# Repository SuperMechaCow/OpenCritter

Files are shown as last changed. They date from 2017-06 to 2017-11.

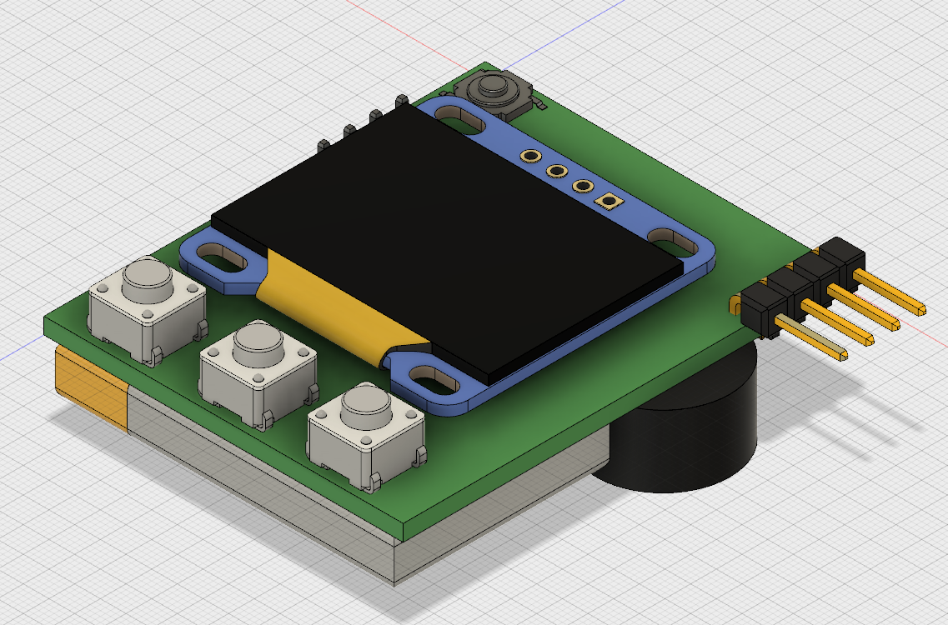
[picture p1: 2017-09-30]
hardware/oc_DevKit2/images/Capture1.PNG

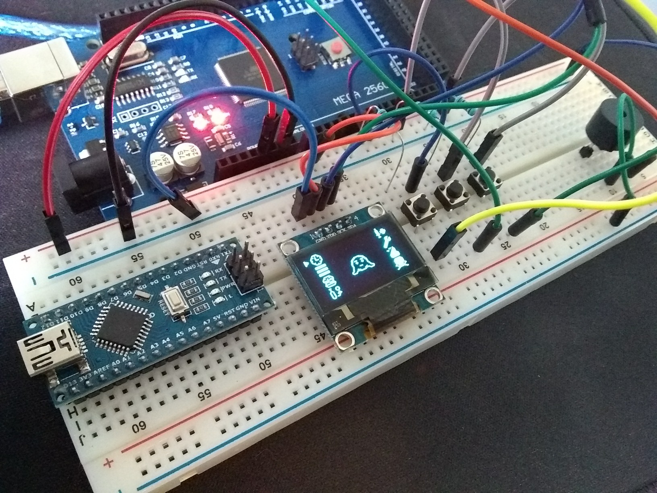
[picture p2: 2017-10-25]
gfx/media/projects/IMG_20171016_145721863.jpg

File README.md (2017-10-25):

# OpenCritter

OpenCritter is an open source digital pet. The software is totally free, and the hardware easy to obtain.

Anyone is invited to work on the project for as long as they stick to the following principles:

- OpenCritter is for all levels of skill and expertise. Novices should be able to build their own from scratch, and experts can lead the project development.
- OpenCritter is all-ages and gender nuetral.
- OpenCritter is for makers *and* hackers. Create and destroy!
- Mods are encouraged! But anything that conflicts with the "core experience" of the game should be listed as a new branch.

## Community

**Main GitHub:**
https://github.com/SuperMechaCow/OpenCritter

**Subreddit:**
https://www.reddit.com/r/OpenCritter/

**Discord Channel:**
https://discord.gg/VW9fjV9

## Community

**Main GitHub:**
https://github.com/SuperMechaCow/OpenCritter

**Subreddit:**
https://www.reddit.com/r/OpenCritter/

**Discord Channel:**
https://discord.gg/VW9fjV9

## Hardware

OpenCritter is currently being developed for ESP-01 and NodeMCU in the Arduino IDE. A branch is being made for Atmega328p-based "Lite" versions.

**DevKit1** has been released. It features an ESP8266 circuit, an alternative header for an ESP-01 module, an Atmega328p circuit, programming headers, and four i2c bus headers.

All platforms will need an I2C 0.96" OLED screen based on SSD1306. Additonal piezo buzzer, a small vibration motor (optional), a battery circuit, and three tactile switches should be used with the platform or as an additional IOPU device.

## Software

Currently, the software requires Adafruit's GFX and SSD1306 libraries, and ESP8266 core arduino software depending on your platform.

## Objectives

- Finish the main game's functionality (sickness/death, crying for attention, evolution, mini-games, game rules)
- Add robust "plug-in device" support for modularity.
- Add peer-to-peer wireless communications
- Multi-player games and functions
- OpenCritter "dog house" device or wireless internet functionality.
- OpenCritter database for online multiplayer/scoreboards.

## How can I contribute?

- Graphic designer? We need sprites and animations for 30 different critters!
- Web front-end developer? We need a more robust and pretty webapp to be hosted by the device itself!
- Web back-end developer? We need a database / highscore table for the pets to connect to/register/sync with!
- 3D CAD? DevKit1 could benefit from some open-source cases!
- Electronics Engineer? We need new i2c modules to add plug-and-play functions to the device!
- Software/Embedded Engineer? The device is always in need of optimization, improved i2c module API, and power-saving features!
- Stickler for details? Documentation constantly needs updated!

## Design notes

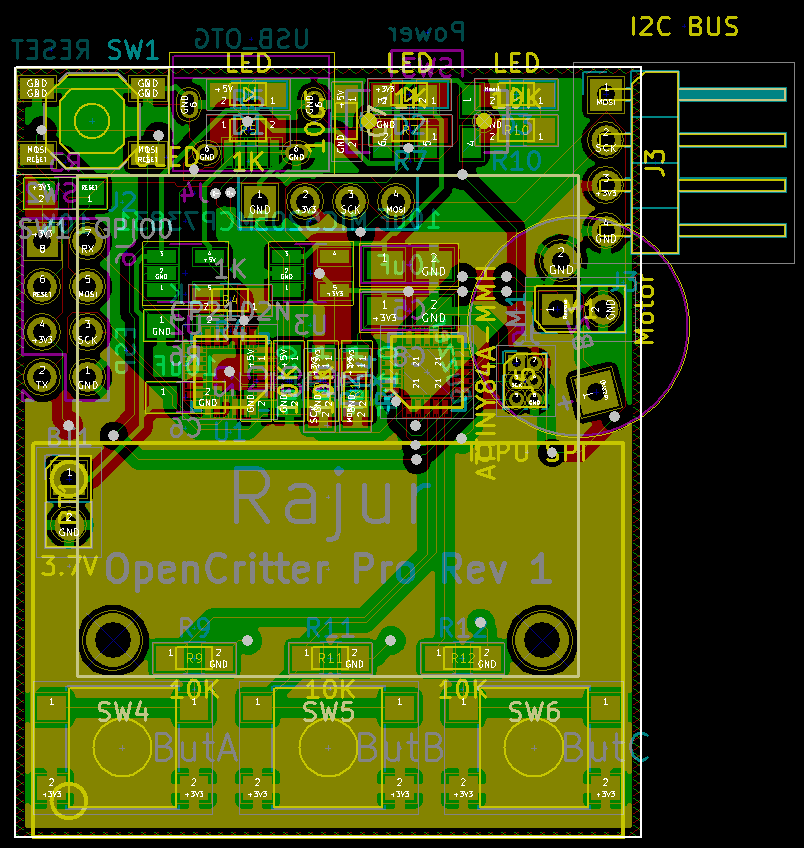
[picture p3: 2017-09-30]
hardware/oc_DevKit2/images/19e5b5ffc640fa55cabdfcedfeb329e0.png

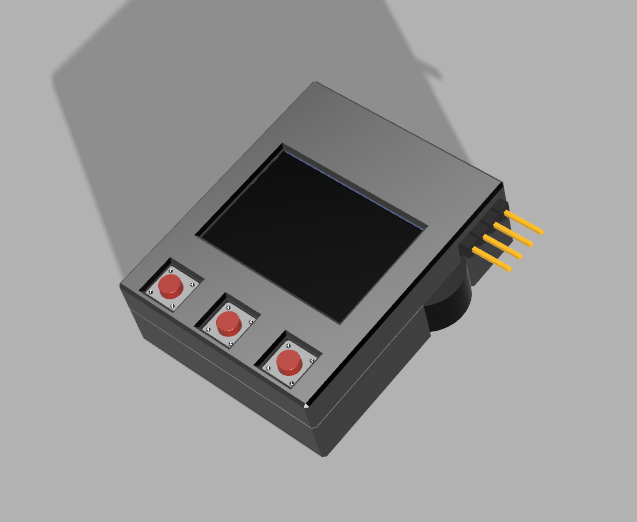
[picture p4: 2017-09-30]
hardware/oc_DevKit2/images/Capture.PNG

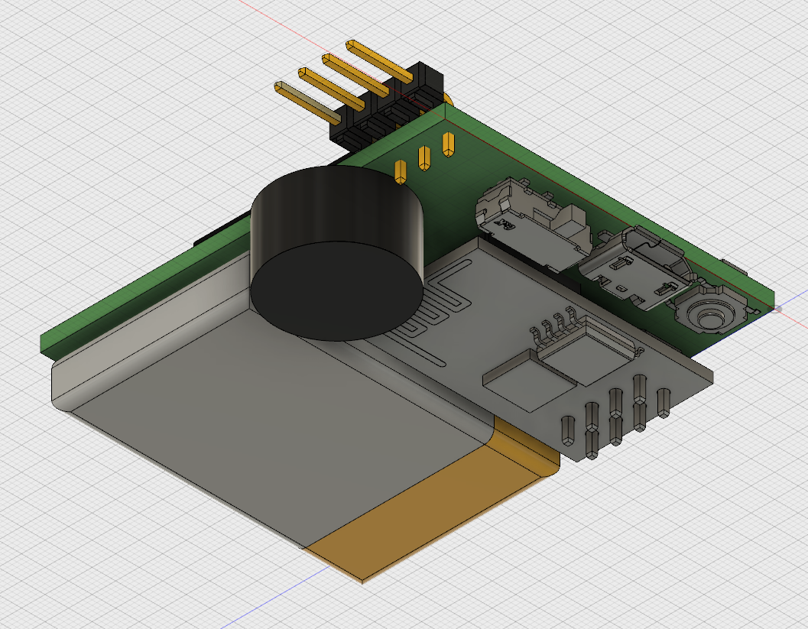
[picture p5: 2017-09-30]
hardware/oc_DevKit2/images/Capture2.PNG

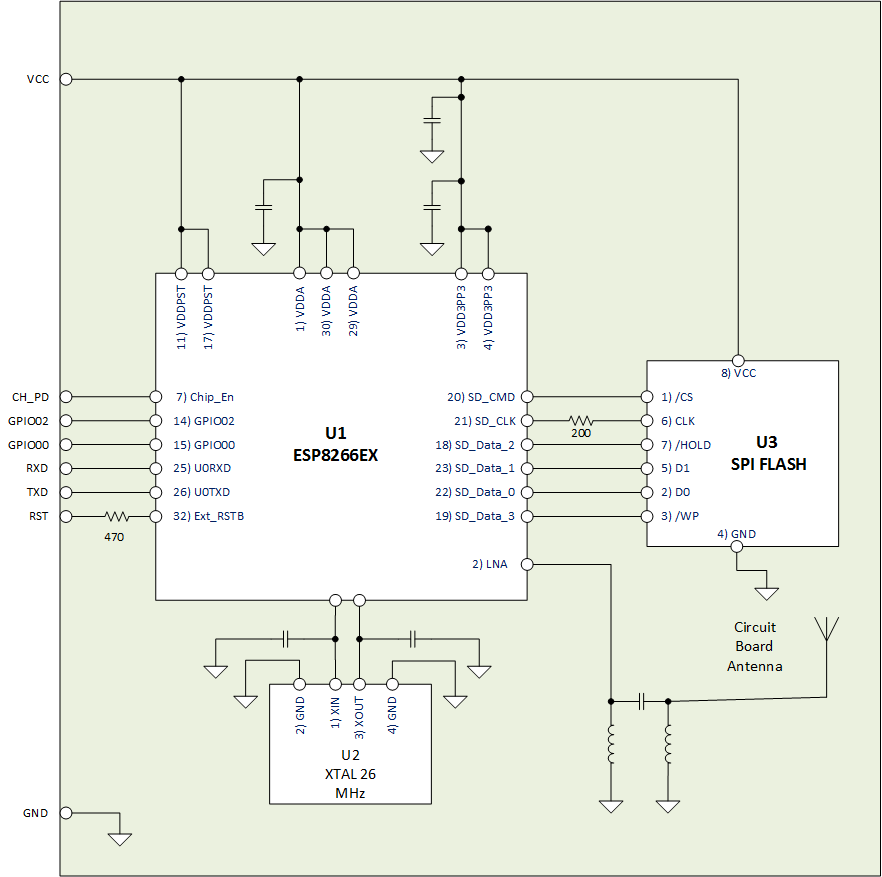
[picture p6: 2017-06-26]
reference/ESP01-Schematic.png

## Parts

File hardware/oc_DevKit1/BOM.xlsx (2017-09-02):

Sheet: Sheet1
version | source | date | tool | number | name | tstamps | title | company | rev | date2 | source3 | number4 | value | ref | value2 | footprint | lib | part | names | tstamps3 | tstamp | datasheet | lib4 | part5 | alias | description | docs | field | name6 | num | name7 | type | fp | logical | uri | code | name8 | ref9 | pin
D | C:/Users/christopher.smith/ownCloud/Projects/OpenCritter/hardware/opencritter_pro/opencritter.sch | 9/1/2017 12:39:36 PM | Eeschema 4.0.6 | 1 | / | / | OpenCritter DevKit1 | MechaMods | 1 | 2017-09-01 | opencritter.sch | 1
D | C:/Users/christopher.smith/ownCloud/Projects/OpenCritter/hardware/opencritter_pro/opencritter.sch | 9/1/2017 12:39:36 PM | Eeschema 4.0.6 | 1 | / | / | OpenCritter DevKit1 | MechaMods | 1 | 2017-09-01 | opencritter.sch | 2
D | C:/Users/christopher.smith/ownCloud/Projects/OpenCritter/hardware/opencritter_pro/opencritter.sch | 9/1/2017 12:39:36 PM | Eeschema 4.0.6 | 1 | / | / | OpenCritter DevKit1 | MechaMods | 1 | 2017-09-01 | opencritter.sch | 3
D | C:/Users/christopher.smith/ownCloud/Projects/OpenCritter/hardware/opencritter_pro/opencritter.sch | 9/1/2017 12:39:36 PM | Eeschema 4.0.6 | 1 | / | / | OpenCritter DevKit1 | MechaMods | 1 | 2017-09-01 | opencritter.sch | 4
D | C:/Users/christopher.smith/ownCloud/Projects/OpenCritter/hardware/opencritter_pro/opencritter.sch | 9/1/2017 12:39:36 PM | Eeschema 4.0.6 | 2 | /IOPU/ | /5984AD37/ | OpenCritter DevKit1 | MechaMods | 1 | 2017-09-01 | IOPU.sch | 1
D | C:/Users/christopher.smith/ownCloud/Projects/OpenCritter/hardware/opencritter_pro/opencritter.sch | 9/1/2017 12:39:36 PM | Eeschema 4.0.6 | 2 | /IOPU/ | /5984AD37/ | OpenCritter DevKit1 | MechaMods | 1 | 2017-09-01 | IOPU.sch | 2
D | C:/Users/christopher.smith/ownCloud/Projects/OpenCritter/hardware/opencritter_pro/opencritter.sch | 9/1/2017 12:39:36 PM | Eeschema 4.0.6 | 2 | /IOPU/ | /5984AD37/ | OpenCritter DevKit1 | MechaMods | 1 | 2017-09-01 | IOPU.sch | 3
D | C:/Users/christopher.smith/ownCloud/Projects/OpenCritter/hardware/opencritter_pro/opencritter.sch | 9/1/2017 12:39:36 PM | Eeschema 4.0.6 | 2 | /IOPU/ | /5984AD37/ | OpenCritter DevKit1 | MechaMods | 1 | 2017-09-01 | IOPU.sch | 4
D | C:/Users/christopher.smith/ownCloud/Projects/OpenCritter/hardware/opencritter_pro/opencritter.sch | 9/1/2017 12:39:36 PM | Eeschema 4.0.6 | 3 | /ESP-01/ | /5984AD3F/ | OpenCritter DevKit1 | MechaMods | 1 | 2017-09-01 | ESP-01.sch | 1
D | C:/Users/christopher.smith/ownCloud/Projects/OpenCritter/hardware/opencritter_pro/opencritter.sch | 9/1/2017 12:39:36 PM | Eeschema 4.0.6 | 3 | /ESP-01/ | /5984AD3F/ | OpenCritter DevKit1 | MechaMods | 1 | 2017-09-01 | ESP-01.sch | 2
D | C:/Users/christopher.smith/ownCloud/Projects/OpenCritter/hardware/opencritter_pro/opencritter.sch | 9/1/2017 12:39:36 PM | Eeschema 4.0.6 | 3 | /ESP-01/ | /5984AD3F/ | OpenCritter DevKit1 | MechaMods | 1 | 2017-09-01 | ESP-01.sch | 3
D | C:/Users/christopher.smith/ownCloud/Projects/OpenCritter/hardware/opencritter_pro/opencritter.sch | 9/1/2017 12:39:36 PM | Eeschema 4.0.6 | 3 | /ESP-01/ | /5984AD3F/ | OpenCritter DevKit1 | MechaMods | 1 | 2017-09-01 | ESP-01.sch | 4
D
D
D
D
D
D
D
D
D
D
D
D
D
D
D
D
D
D
D
D
D
D
D
D
D
D
D
D
D
D
D
D
D
D
D
D
D
D
D
D
D
D
D
D
D
D
D
D
D
D
D
D
D
D
D
D
D
D
D
D
D
D
D
D
D
D
D
D
D
D
D
D
D
D
D
D
D
D
D
D
D
D
D
D
D
D
D
D
D
D
D
D
D
D
D
D
D
D
D
D
D
D
D
D
D
D
D
D
D
D
D
D
D
D
D
D
D
D
D
D
D
D
D
D
D
D
D
D
D
D
D
D
D
D
D
D
D
D
D
D
D
D
D
D
D
D
D
D
D
D
D
D
D
D
D
D
D
D
D
D
D
D
D
D
D
D
D
D
D
D
D
D
D
D
D
D
D
D
D
D
D
D
D
D
D
D
D
D
D
D
D
D
D
D
D
D
D
D
D
D
D
D
D
D
D
D
D
D
D
D
D
D
D
D
D
D
D
D
D
D
D
D
D
D
D
D
D
D
D
D
D
D
D
D
D
D
D
D
D
D
D
D
D
D
D
D
D
D
D
D
D
D
D
D
D
D
D
D
D
D
D
D
D
D
D
D
D
D
D
D
D
D
D
D
D
D
D
D
D
D
D
D
D
D
D
D
D
D
D
D
D
D
D
D
D
D
D
D
D
D
D
D
D
D
D
D
D
D
D
D
D
D
D
D
D
D
D
D
D
D
D
D
D
D
D
D
D
D
D
D
D
D
D
D
D
D
D
D
D
D
D
D
D
D
D
D
D
D
D
D
D
D
D
D
D
D
D
D
D
D
D
D
D
D
D
D
D
D
D
D
D
D
D
D
D
D
D
D
D
D
D
D
D
D
D
D
D
D
D
D
D
D
D
D
D
D
D
D
D
D
D
D
D
D
D
D
D
D
D
D
D
D
D
D
D
D
D
D
D
D
D
D
D
D
D
D
D
D
D
D
D
D
D
D
D
D
D
D
D
D
D
D
D
D
D
D
D
D
D
D
D
D
D
D
D
D
D
D
D
D
D
D
D
D
D
D
D
D
D
D
D
D
D
D
D
D
D
D
D
D
D
D
D

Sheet: Sheet2
ref | value5 | footprint | part | names | datasheet
AE1 | Antenna |  | Antenna | /ESP-01/
BT1 | Batter |  | Battery_Cell | /
BZ1 | Buzzer | Buzzers_Beepers:BUZZER | 490-4698-ND | /IOPU/ | http://www.murata.com/~/media/webrenewal/support/library/catalog/products/sound/p37e.ashx | https://www.digikey.com/product-detail/en/murata-electronics-north-america/PKM13EPYH4000-A0/490-4698-ND/1219329
C1 | 0.1uF | Capacitors_SMD:C_0805_HandSoldering | C | /IOPU/
C2 | 0.1uF | Capacitors_SMD:C_0805_HandSoldering | C | /IOPU/
C3 | 0.1uF | Capacitors_SMD:C_0805_HandSoldering | C | /IOPU/
C4 | C | Capacitors_SMD:C_0805_HandSoldering | C | /ESP-01/
C5 | C | Capacitors_SMD:C_0805_HandSoldering | C | /ESP-01/
C6 | C | Capacitors_SMD:C_0805_HandSoldering | C | /ESP-01/
C7 | C | Capacitors_SMD:C_0805_HandSoldering | C | /ESP-01/
C8 | C | Capacitors_SMD:C_0805_HandSoldering | C | /ESP-01/
D1 | LED | LEDs:LED_0805_HandSoldering | 732-4982-1-ND | /IOPU/ | http://katalog.we-online.de/led/datasheet/150080BS75000.pdf | https://www.digikey.com/product-detail/en/wurth-electronics-inc/150080BS75000/732-4982-1-ND/4489910
J1 | ESP UART | Pin_Headers:Pin_Header_Straight_1x04_Pitch2.54mm | S1012EC-22-ND | / | https://media.digikey.com/PDF/Data%20Sheets/Sullins%20PDFs/z%20RzCzzzSzzN-RC,%20ST,11635-B.pdf | https://www.digikey.com/product-detail/en/sullins-connector-solutions/PREC022SAAN-RC/S1012EC-22-ND/2774832
J10 | ESP Header |  |  | /ESP-01/
J11 | ESP GPIO | Pin_Headers:Pin_Header_Straight_1x08_Pitch2.54mm | J1 | /ESP-01/
J2 | 328 SPI | Pin_Headers:Pin_Header_Straight_2x03_Pitch2.54mm | J1 | /
J3 | OLED |  |  | /
J4 | 328 GPIO | Pin_Headers:Pin_Header_Straight_1x06_Pitch2.54mm | J1 | /
J5 | I2C BUS | Pin_Headers:Pin_Header_Angled_1x04_Pitch2.54mm | S1112EC-16-ND | / | https://media.digikey.com/PDF/Data%20Sheets/Sullins%20PDFs/zzzCzzzSzzN-M71RC,%2011637-B.pdf | https://www.digikey.com/product-detail/en/sullins-connector-solutions/PREC016SBAN-M71RC/S1112EC-16-ND/2774918
J6 | 328 UART | Pin_Headers:Pin_Header_Straight_1x04_Pitch2.54mm | J1 | /
J7 | I2C BUS | Pin_Headers:Pin_Header_Angled_1x04_Pitch2.54mm | J5 | /
J8 | I2C BUS | Pin_Headers:Pin_Header_Angled_1x04_Pitch2.54mm | J5 | /
J9 | I2C BUS | Pin_Headers:Pin_Header_Angled_1x04_Pitch2.54mm | J5 | /
JP1 | RxX |  |  | /
JP2 | TxX |  |  | /
JP3 | Enable |  |  | /ESP-01/
L1 | L | Inductors_SMD:L_0805_HandSoldering | L | /ESP-01/
L2 | L | Inductors_SMD:L_0805_HandSoldering | L | /ESP-01/
M1 | Motor | Pin_Headers:Pin_Header_Straight_1x02_Pitch2.54mm | Motor_DC | /IOPU/
R1 | 10K | Resistors_SMD:R_0805_HandSoldering | R | /IOPU/ | https://riedon.com/media/pdf/ASC.pdf | https://www.digikey.com/product-detail/en/riedon/ASC0805-10KF1/696-1785-1-ND/7398755
R10 | 12K | Resistors_SMD:R_0805_HandSoldering | R | /ESP-01/
R11 | 10K | Resistors_SMD:R_0805_HandSoldering | R | / | https://riedon.com/media/pdf/ASC.pdf | https://www.digikey.com/product-detail/en/riedon/ASC0805-10KF1/696-1785-1-ND/7398755
R12 | 10K | Resistors_SMD:R_0805_HandSoldering | R | / | https://riedon.com/media/pdf/ASC.pdf | https://www.digikey.com/product-detail/en/riedon/ASC0805-10KF1/696-1785-1-ND/7398755
R2 | 10K | Resistors_SMD:R_0805_HandSoldering | R | /IOPU/ | https://riedon.com/media/pdf/ASC.pdf | https://www.digikey.com/product-detail/en/riedon/ASC0805-10KF1/696-1785-1-ND/7398755
R3 | 10K | Resistors_SMD:R_0805_HandSoldering | R | /IOPU/ | https://riedon.com/media/pdf/ASC.pdf | https://www.digikey.com/product-detail/en/riedon/ASC0805-10KF1/696-1785-1-ND/7398755
R4 | 10K | Resistors_SMD:R_0805_HandSoldering | R | /IOPU/ | https://riedon.com/media/pdf/ASC.pdf | https://www.digikey.com/product-detail/en/riedon/ASC0805-10KF1/696-1785-1-ND/7398755
R5 | 10K | Resistors_SMD:R_0805_HandSoldering | R | /IOPU/ | https://riedon.com/media/pdf/ASC.pdf | https://www.digikey.com/product-detail/en/riedon/ASC0805-10KF1/696-1785-1-ND/7398755
R6 | 10K | Resistors_SMD:R_0805_HandSoldering | R | /ESP-01/ | https://riedon.com/media/pdf/ASC.pdf | https://www.digikey.com/product-detail/en/riedon/ASC0805-10KF1/696-1785-1-ND/7398755
R7 | 10K | Resistors_SMD:R_0805_HandSoldering | R | /ESP-01/ | https://riedon.com/media/pdf/ASC.pdf | https://www.digikey.com/product-detail/en/riedon/ASC0805-10KF1/696-1785-1-ND/7398755
R8 | 200 | Resistors_SMD:R_0805_HandSoldering | R | /ESP-01/
R9 | 470 | Resistors_SMD:R_0805_HandSoldering | R | /ESP-01/
SW1 | ButA | Buttons_Switches_SMD:SW_SPST_SKQG | CKN9104CT-ND | /IOPU/ | http://www.ckswitches.com/media/1467/pts525.pdf | https://www.digikey.com/product-detail/en/c-k/PTS525SM15SMTR2-LFS/CKN9104CT-ND/1146923
SW2 | ButB | Buttons_Switches_SMD:SW_SPST_SKQG | CKN9104CT-ND | /IOPU/ | http://www.ckswitches.com/media/1467/pts525.pdf | https://www.digikey.com/product-detail/en/c-k/PTS525SM15SMTR2-LFS/CKN9104CT-ND/1146923
SW3 | ButC | Buttons_Switches_SMD:SW_SPST_SKQG | CKN9104CT-ND | /IOPU/ | http://www.ckswitches.com/media/1467/pts525.pdf | https://www.digikey.com/product-detail/en/c-k/PTS525SM15SMTR2-LFS/CKN9104CT-ND/1146923
SW4 | RESET | Buttons_Switches_SMD:SW_SPST_SKQG | CKN9104CT-ND | /IOPU/ | http://www.ckswitches.com/media/1467/pts525.pdf | https://www.digikey.com/product-detail/en/c-k/PTS525SM15SMTR2-LFS/CKN9104CT-ND/1146923
SW5 | GPIO0 | Buttons_Switches_SMD:SW_SPST_EVQPE1 | P13593SCT-ND | /ESP-01/ | http://industrial.panasonic.com/cdbs/www-data/pdf/ATK0000/ATK0000CE7.pdf | https://www.digikey.com/product-detail/en/panasonic-electronic-components/EVQ-PE104K/P13593SCT-ND/1245514
SW6 | RESET | Buttons_Switches_SMD:SW_SPST_EVQPE1 | P13593SCT-ND | /ESP-01/ | http://industrial.panasonic.com/cdbs/www-data/pdf/ATK0000/ATK0000CE7.pdf | https://www.digikey.com/product-detail/en/panasonic-electronic-components/EVQ-PE104K/P13593SCT-ND/1245514
U1 | ATMEGA328P-AU | Housings_QFP:TQFP-32_7x7mm_Pitch0.8mm | ATMEGA328P-AURCT-ND | /IOPU/ | http://www.atmel.com/images/Atmel-8271-8-bit-AVR-Microcontroller-ATmega48A-48PA-88A-88PA-168A-168PA-328-328P_datasheet_Complete.pdf | https://www.digikey.com/product-detail/en/microchip-technology/ATMEGA328P-AUR/ATMEGA328P-AURCT-ND/3789455
U2 | ESP8266EX | Housings_DFN_QFN:QFN-32-1EP_5x5mm_Pitch0.5mm | ESP8266EX | /ESP-01/
U3 | CAT250 | Housings_SOIC:SOIC-8_3.9x4.9mm_Pitch1.27mm | CAT25040VI-GT3CT-ND | /ESP-01/ | http://www.onsemi.com/pub/Collateral/CAT25010-D.PDF | https://www.digikey.com/product-detail/en/on-semiconductor/CAT25040VI-GT3/CAT25040VI-GT3CT-ND/1631168
Y1 | 16Mhz | Crystals:Crystal_SMD_3225-4pin_3.2x2.5mm_HandSoldering | SER3686CT-ND | /IOPU/ | https://support.epson.biz/td/api/doc_check.php?dl=brief_FA-238V_en.pdf | https://www.digikey.com/product-detail/en/epson/FA-238-16.0000MB-C3/SER3686CT-ND/2403459
Y2 | 40Mhz | Crystals:Crystal_SMD_3225-4pin_3.2x2.5mm_HandSoldering |  | /ESP-01/ | https://www.diodes.com/assets/Datasheets/FL.pdf | https://www.digikey.com/product-detail/en/diodes-incorporated/FL4000157Z/FL4000157ZTR-ND/6049193

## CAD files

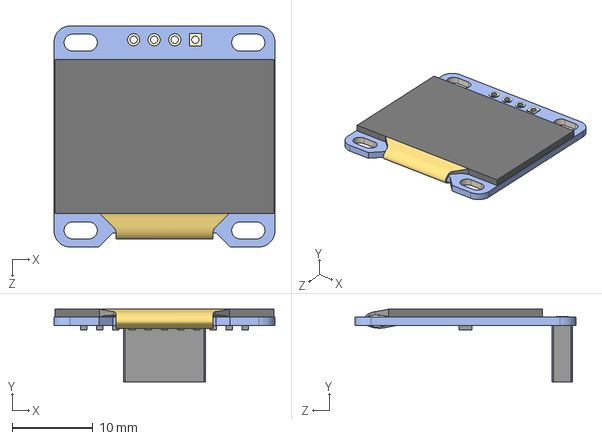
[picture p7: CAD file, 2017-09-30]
hardware/models/OLED_27x27_r2.STEP
27.3 x 9.00 x 27.3 mm

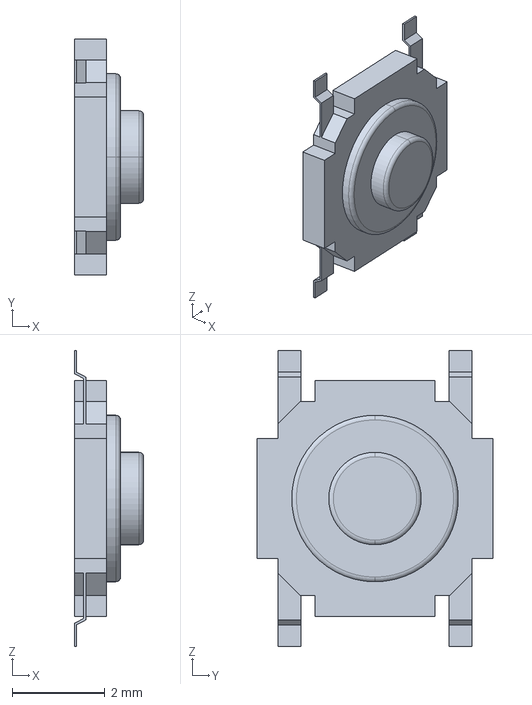
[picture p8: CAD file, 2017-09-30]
hardware/models/Y97CT23B5CCFP.stp
1.50 x 5.10 x 6.40 mm

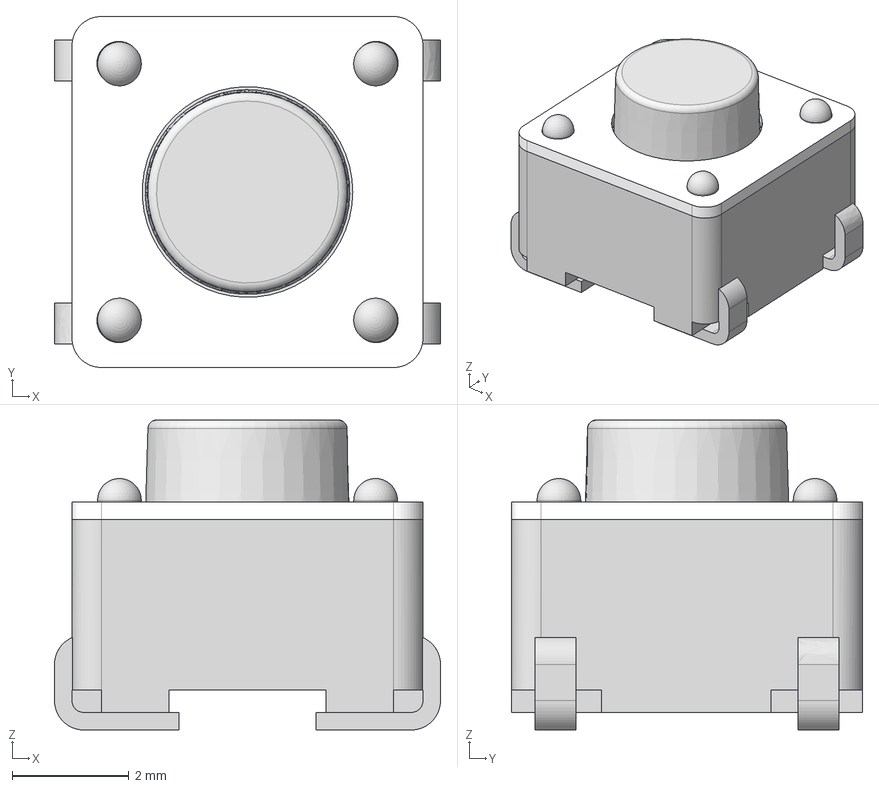
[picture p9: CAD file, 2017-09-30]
hardware/models/TL3301AFxxxxJ.stp
6.60 x 6.00 x 5.30 mm
TL1105CONTACTDOME
TL3301JBODY
TL1105COVER
TL1105-3301ACTUATOR A 5

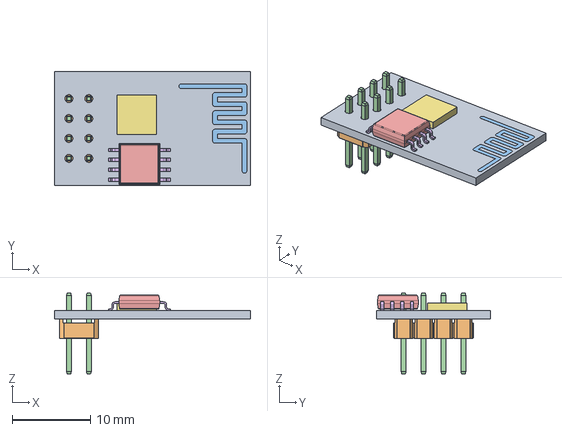
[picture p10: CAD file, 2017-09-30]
hardware/models/ESP8266-ESP01.stp
25.0 x 14.5 x 10.3 mm

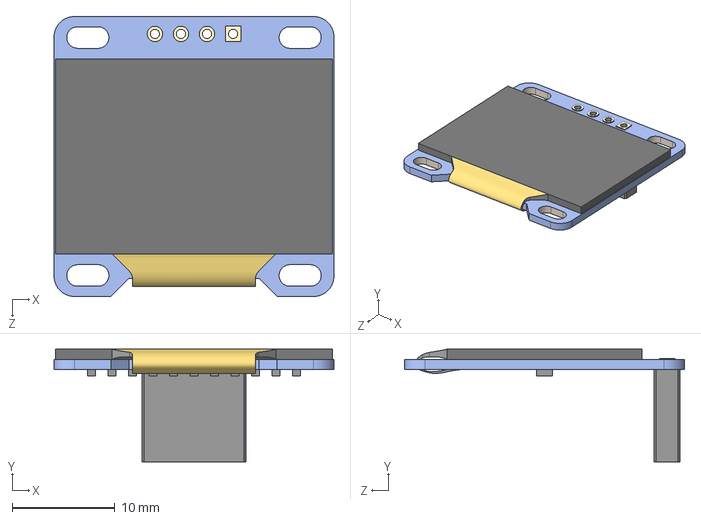
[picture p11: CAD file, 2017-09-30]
hardware/models/OLED_27x27.STEP
27.3 x 11.0 x 27.3 mm

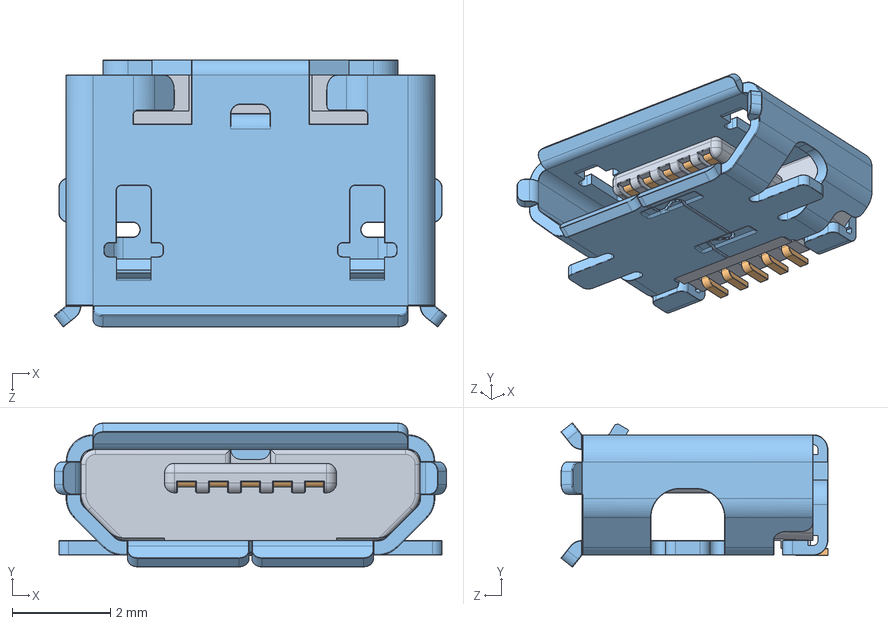
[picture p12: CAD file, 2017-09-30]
hardware/models/micro USB.STEP
7.97 x 2.92 x 5.43 mm
micro usb02
micro usb

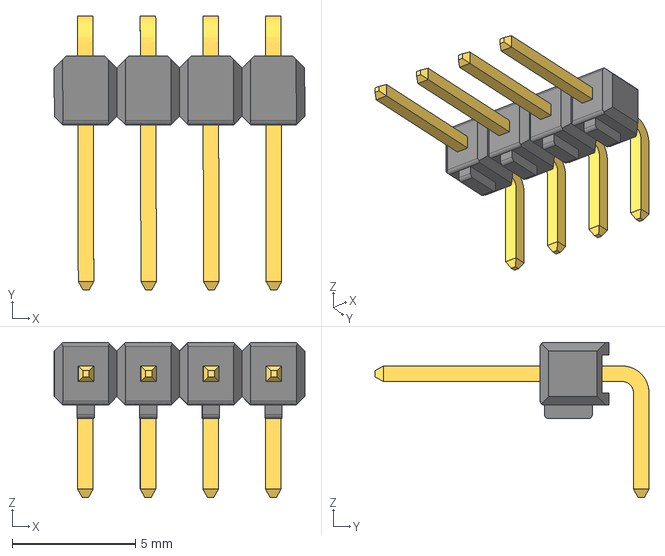
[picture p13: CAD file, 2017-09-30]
hardware/models/Pin Header 1x4 TH Angle Pitch 2.54mm.stp
10.2 x 11.1 x 6.29 mm

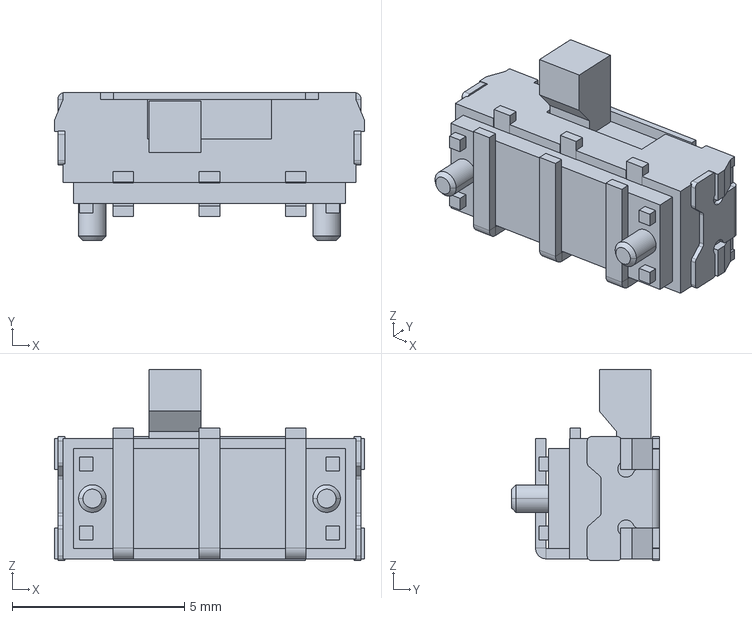
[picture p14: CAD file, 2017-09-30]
hardware/models/js102011jaqn.stp
9.00 x 4.30 x 5.55 mm

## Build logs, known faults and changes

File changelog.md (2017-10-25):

### October 24th, 2017 [alpha v0.013] Adults Update

[Changes]
- Added nine new adult breeds: Culu, Shent, Slorp, Zeta, Butters, Corine, Pyre, Rajur, and Crosh.
- Greatly reduced evolvehandler() code.
- Put breed selection for animations and frame fetching back in.
- Added icon graphics "labk", "book", "biok" and "tome".
- Fixed code that incorrectly read the incoming button byte from IOPUs. You can now press two buttons at once.
- Added "debug button" IOPU sketch that adds a fourth button (pin A1) to the game for debugging purposes.
- Changed Lazer Chiken to Lazer Jet.
- Added beep_noise to IOPU for Lazer Jet game.
- Added Soda effect. Boosts metabolism for 1000 heartbeats.
- Added Star item. Adds double food bonus to all health stats without penalty.
- Added Bio Kit item. Shows numerical values of all stats.
- Added a "Pedia" item that shows details about each critter.
- Stats numbers are now hidden, showing only bars.
- Making a "discovery" now has equal chances of finding Meds, Soda, or a Star
- Critter can now walk around the "playpen" when on the main menu.
- Fixed games menu not selecting BitShifter

[Known Bugs]
- Some of the adults may not be able to be evolved into naturally through gameplay.
- The Lab Kit is in the game, but currently does nothing.

### October 18th, 2017 [alpha v0.012] Inventory Update

Inventory system was added!

Some much-needed change to terminology was done to reduce the confusing game mechanics!

Animation frame selection was reworked to save a lot of space and time! Reduced lines of code from 1,111 to 172!

[Changes]
- Removed "use Medicine" option and replaced with the Inventory Menu (icon is the same).
- Added "Meds" item to Inventory.
- Added "Soda" to item Inventory, but it has no effect yet.
- When the critter's Energy bar is full, it will drain down to it's health bar's status and add one Meds to your inventory.
- Energy bar now increases with heartbeat in addition to health stat drain.
- Removed aniModeSet() and went back to just using aniMode.
- getFrame() can now fetch the frame's name of the current breed depending on what anaimation frame you want.
- Animations now just assume you want to use the animations for your current breed.
- Critter parameters are now broken into Energy, Health, and Power categories (previously BioSpecs, Health, and Traits).
- Every critter parameter is now a "stat" of it's "category". (Stats are now "health stats", Traits are now "power stats", and BioSpecs are now "Energy stats").
- In addition, "Energy", "Health", and "Power" are their own stats, derived from a combination of the respective category's stats.
- Split the stats menu into four pages to easily visualize.
- Power stats now scale from 1 to 255 instead of 1 to 100 for consistency's sake.
- Critters can not gain more than twice their nominal weight (nominal_w * 2).
- OLED will turn off to save power after two minutes of no buttons being pressed. Press any button to turn on.
- Added 9 new icon graphics. balf, ball, carb, fats, jetl, jetr, pack, pail, soda.
- Fixed up BitShifter's UI. Added a guide and new graphics. Fixed animation flickering on button press.
- BitShifter now switched to a hexidecimal number after 3 consecutive won rounds.
- Finished graphics for BallCatch.
- Fixed up Card Flip UI. Added score and other graphics.
- Card Flip is now the best of 5 flips. You still receive rewards for each card guessed correctly, but only if you guess more than 3 of the five slips correctly.
- Added lazerchiken as a "hidden game" in the games menu.
- Selecting the Alert icon will take you to the Stats menu if the critter is actually in danger of being sick.
- Merged both versions of E_humanIO_* into E_InputOutput. Now each function can tell if the board has it's own IO or there is an IOPU attached.
- Switched position of I_animate and J_games to I_games and J_animate to keep similar functions together.
- Added evolution and death animations.

[Known Bugs]
- Pressing both A and B with cancel playing a game?
- Button presses are sometimes repeating without being released, esepcially on various submenus.
- OLED sometimes gets stuck off. Not sure of the cause yet.

### September 24th, 2017 [alpha v0.011] Teenager Update

[Changes]
- Added 7 new breeds (two babies and five teenagers): xorby, goob, moops, shansy, hwooty, lugerd, and flip.
- Which baby you get is now determined by the highest STAT of the egg when hatching
- Teens are now determined by the lowest trait, and if that lowest trait is above or below 50
- Finally fixed eating animation to always match current breed!
- Cleaned up debug-over-serial console
- Bit Shifter now has a title screen and scorekeeper. After three points the game switches the decimal number to hexadecimal. Costs 10 Energy to play.

[Known Bugs]
- Hwooty's eye is a little weird, lol

[Repo Changes]
- Tweaked folder structure. Most folders contain a text file explaining the contents thereof.
- Added files for work-in-progress files for OpenCritter Pro 1, a practical, playable version of the hardware.
- Added evolution_graphics.png and evolution_params.png to /gfx/ folder for reference. Gimp files in /gfx/gimp/

### September 12th, 2017 [alpha v0.010] Minor

[Changes]
- WiFi can now be toggled to save power
- Atmega328 IOPU button pins switched due to fix error in DevKit1
- Getting buttons from IOPU over i2c now uses 1 byte instead of 8
- Critter can now die from having more than four stacks of sickness
- Added new *unfinished* "Lazer Chiken" game. Enable "debugMode" and select Ball Catcher to play.

[Known Bugs]
- Wifi Enable/Disable is buggy. Does not always enable WiFi
- Changing the beeper mute status also changes the buzzer mute status for some reason

### September 6th, 2017 [alpha v0.009] Major
Wifi + Play Update

[Changes]
- ESP-01 and NodeMCU now broadcast a soft Access Point, where users can connect and interact through a web browser!
- Added Ball Catch Minigame
- Food (now Protein, Fat, and Carbs) now complete!
- Games now complete!
- Added Energy. Each time a stat drain Energy charges by one. In the future, this will be used to play games and if left full can be automatically used to find meds and loot
- Protein rolls against Ath to gain 1 weight, charges hun, and drains Ath.
- Fat rolls against Ath to gain 1 weight, adds 1 weight, greatly charges hap, and drains Dis.
- Carbs rolls against Ath to gain 1 weight, adds 1 weight, greatly charges bor, and drains Int.
- Ball Catch charges Ath, and drains/charges weight closer to a healthy weight.
- Card Flip charges hap and Dis.
- Bitshifter charges bor and Int.
- Food and Games menus now show what stats are changed by playing.
- Fixed a bug that allowed muted sounds to play
- Fixed animations in games
- Added animation to bitshifter
- animate() now passes X and Y values for the position of the animation
- Moved location of some critter parameters around (breed and metabolism to Clock menu. Energy and Health bars to Biospecs)

### September 1st, 2017 [alpha v0.008]

[Changes]
- Add KiCad schematics, pcb layout, and gerber files for the upcoming DevKit1
- Started sketch for IOPU based on Attiny
- Seeedstudio Fusion project published for DevKit1, so anyone can easily purchase PCBs for it.
	https://www.seeedstudio.com/undefined-g-1040190

### August 2nd, 2017 [alpha v0.007]

[Changes]
- Added lifestages counter (egg, baby, teen, adult, senior... "ancient?").
- The "sickness threshold" is now calculated by how sick the critter already is, how much poop is on the floor, and what "life stage" the critter is at.
- Critter will now cry for attention if its stats and Dis are low
- Criter will now cry when it is in danger of becoming sick
- Sound alerts for becoming sick or pooping

### August 1st, 2017 [alpha v0.006] Nightly

[Changes]
- Stats will no longer roll around to 255 when reducing past 0.
- Added "sick" feature. If stats are left below an average of 100 there's a chance every X heartbeats to gain an illness.
- Medicine menu now removes one illness (this is to made finite later)
- Critters can now poop. The heavier the critter, the more likely it is to poop.
- Poop menu now removes one poop.
- Each stage of life (egg, baby, teen, adult, senior) has a different metabolism bonus
- Metabolism calculation has changed. Is now the average of the average of stats, the average of traits, and the metabolic bonus.
- Critter now evolves every X heartbeats in a linear list of breeds. Variable evolution will be handled in later versions.
- Fixed eating animations (distorted burger icon).
- Added "Tribbur" and "Snek" breeds back into the game.
- Fixed some issues with food subtracting stats rather than adding.

### July 27th, 2017 [alpha v0.005] Major

[Changes]
- Project is now design for ESP-01 with OLED and an Input/Output Processing Unit ("IOPU" device) or a NodeMCU
- Scope of project became too large to run on an Atmega328, so a branch was made for "OpenCritter Lite"
- heartbeat "rolls" now "pile up" so they can be resolved later. This means delay() can now be used in animations, etc. without skipping important heartbeat events
- Started addding support for hardware modules on the I2C bus. This includes scanning and identification of plugged in devices. However, only hard-coded IOPU works right now.
- Real clock is now adjusted by a single offset parameter, rather than by hour/minute/seconds seperately

[Known Bugs]
- Too much serial data seems to interfere with I2C bus comms. Most serial debugging verbosity commented out to "fix" this.

[Notes]

### June 29th, 2017 [alpha v0.004] Nightly

[Changes]
- Change data types of Stats and Traits to save bytes
- Metabolism is the average percent of your stats and traits + the deviation from "healthy" weight
- Stats roll to drain every X hearbeats, depending on corresponding trait. The higher the trait, the slower it drains.
- Now rolls to see if you will gain weight each time you feed it, depending on Ath
- Added EEPROM writer tool to dump the gfx arrays header file into on-board EEPROM. Temporary solution until external EEPROM is added.
- Bitmaps are now pulled from EEPROM using the getGFX() function.

[Known Bugs]
- No known bugs fixed from alpha v0.002
- CRITTER BITMAPS ARE ALL BORKED! PANIC!
- This version not updated for ESP8266 platform.

[Notes]
- Disabled buzzer code to make room on the Atmega328

### June 28th, 2017 [alpha v0.003] Nightly

[Changes]
- Added playMenu functionality
- Added bitshifter minigame
- Changed Stats from 0.00 - 100.00 (float) to 0 - 10000 (int)
- Changed Traits from 0.00 - 1.00 (float) to 0 - 100 (byte)

[Known Bugs]
- No known bugs fixed from alpha v0.002
- Stats and Traits changes are untested!!! 

[Notes]
- Atmega328 version is at 98% flash usage! Yikes!
- Some unused icons and gfx disabled to fit program onto Atmega328
- Time offset should be a single modifier to the baseCLK instead of multiple variables

### June 27th, 2017 [alpha v0.002] Nightly

[Changes]
- Added clock set in configuration menu
- Clock Menu now shows lifespan and current time seperate
- Added cardflip game.
- Games are handled like menus with selMenu, but functions are seperated into games tab.
- Updated README.MD

[Known Bugs]
- Atmega328 has unusual behavior when changing from gameStage 3 to 4 in cardflip. Changes gameVal[nextcard] to incrementing semi-random number that seems to depend on time.
- Master (real time) clock doesn't change other units (hours, minutes) when rolling over current unit 

### June 26th, 2017 [alpha v0.001] Nightly

- Started github project

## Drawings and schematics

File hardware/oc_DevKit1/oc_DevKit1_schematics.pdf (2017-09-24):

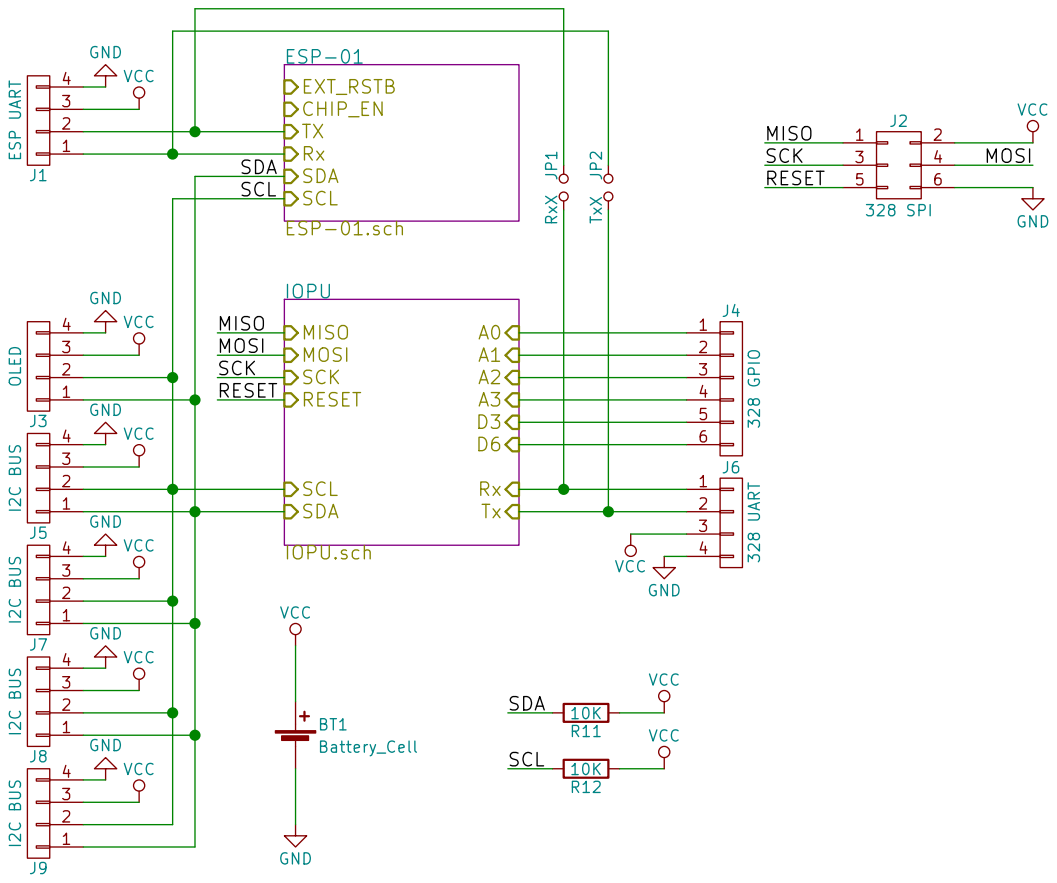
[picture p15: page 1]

File: opencritter.sch Sheet: / MechaMods

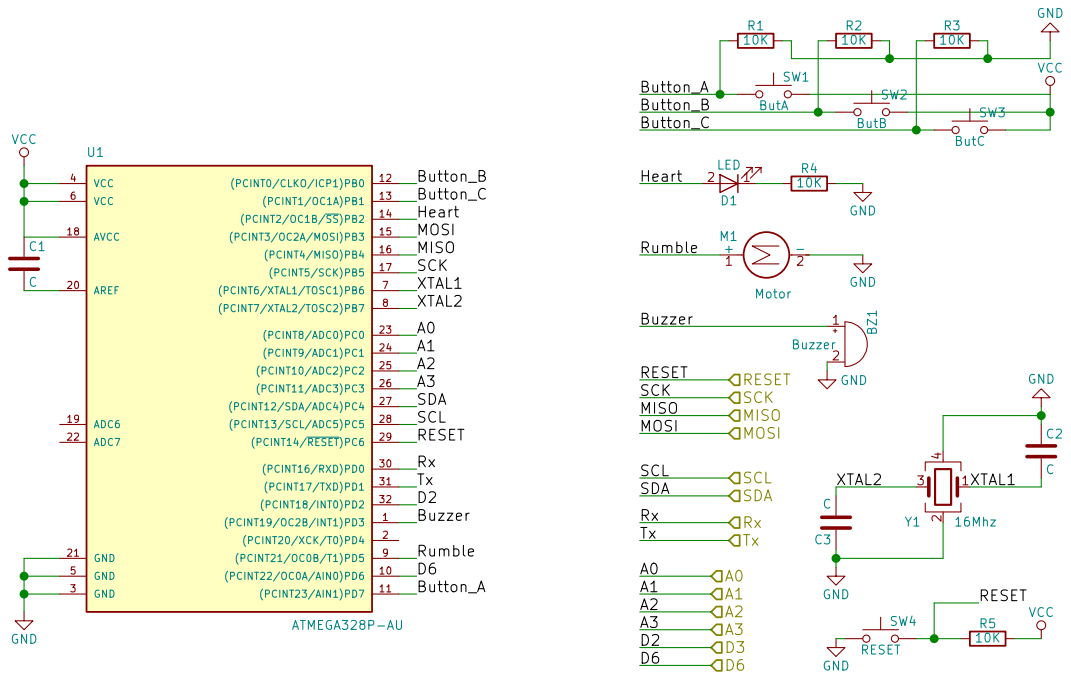
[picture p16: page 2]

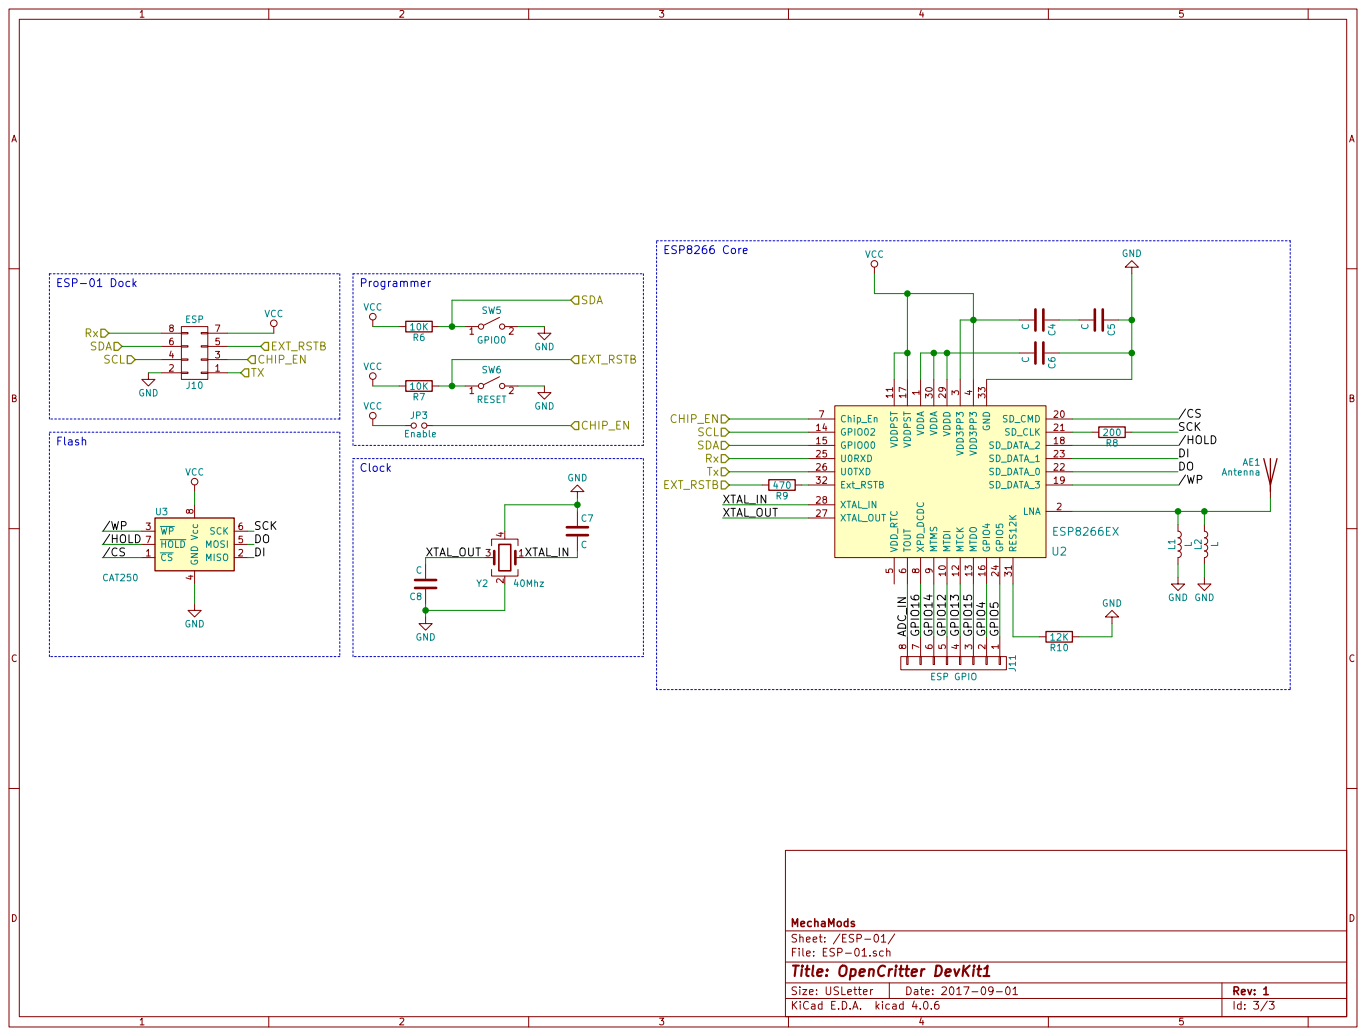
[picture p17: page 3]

9 MTDI 10 SD_CMD 20 VDDA 30 VDDPST 11 SD_CLK 21 RES12K 31 MTCK 12 SD_DATA_0 22 Ext_RSTB 32 MTDO 13 SD_DATA_1 23 GND 33 GPIO02 14 GPIO5 24 GPIO00 15 U0RXD 25 GPIO4 16 U0TXD 26 VDDPST 17 XTAL_OUT 27 SD_DATA_2 18 XTAL_IN 28 SD_DATA_3 19 VDDD 29 U2ESP8266EX

4 MOSI 5 SCK 6 HOLD 7 Vcc U3 8 CAT250 GND
/HOLD

File: ESP-01.sch Sheet: /ESP-01/ MechaMods

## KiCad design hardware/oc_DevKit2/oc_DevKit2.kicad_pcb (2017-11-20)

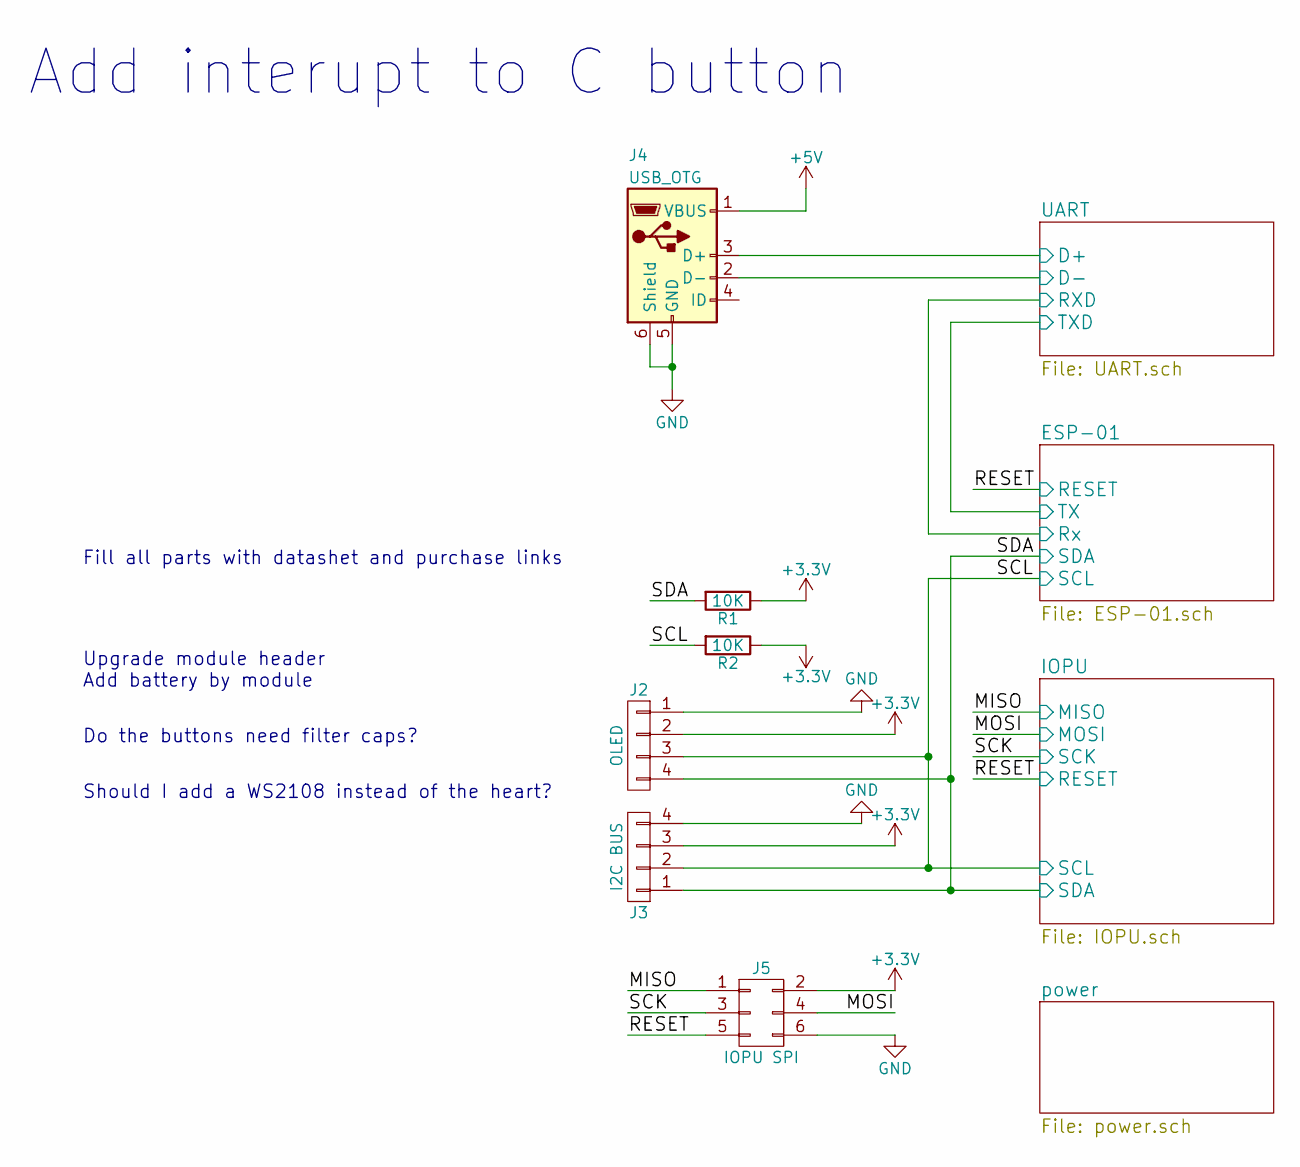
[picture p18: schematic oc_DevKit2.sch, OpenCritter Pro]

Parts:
J2: OLED; SSD1306_i2c
J3: I2C BUS; Pin_Header_Angled_1x04_Pitch2.54mm
J4: USB_OTG; USB_Micro-B
J5: IOPU SPI; Pin_Header_Straight_2x03_Pitch1.00mm
R1, R2: 10K; R_0805_HandSoldering

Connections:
+3V3: J2.2, J3.3, J5.2, R1.1, R2.1; also elsewhere on the board
+5V: J4.1 (VBUS); also elsewhere on the board
/MISO: J5.1; also elsewhere on the board
/MOSI: J2.4, J3.1, J5.4, R1.2; also elsewhere on the board
/RESET: J5.5; also elsewhere on the board
/SCK: J2.3, J3.2, J5.3, R2.2; also elsewhere on the board
/UART/D+: J4.3 (D+); also elsewhere on the board
/UART/D-: J4.2 (D-); also elsewhere on the board
GND: J2.1, J3.4, J4.5 (GND), J4.6 (Shield), J5.6; also elsewhere on the board

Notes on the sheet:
Fill all parts with datashet and purchase links
Upgrade module header Add battery by module
Do the buttons need filter caps?
Should I add a WS2108 instead of the heart?
Add interupt to C button

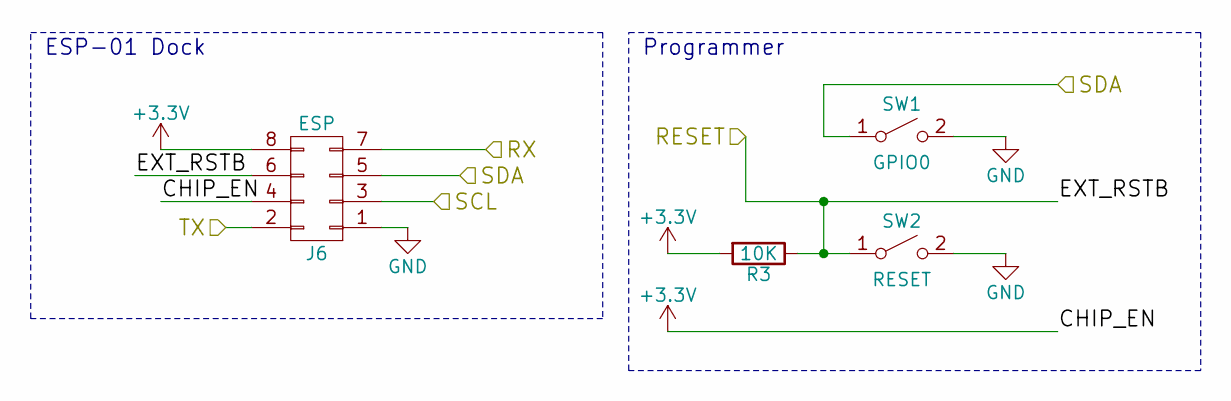
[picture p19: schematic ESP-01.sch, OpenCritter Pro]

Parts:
J6: ESP; ESP-01
R3: 10K; R_0805_HandSoldering
SW1: GPIO0; SW_SPST_SKQG
SW2: RESET; SW_SPST_SKQG

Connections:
+3V3: J6.4, J6.8, R3.2; also elsewhere on the board
/ESP-01/RX: J6.7; also elsewhere on the board
/ESP-01/TX: J6.2; also elsewhere on the board
/MOSI: J6.5, SW1.1 (A); also elsewhere on the board
/RESET: J6.6, R3.1, SW2.1 (A); also elsewhere on the board
/SCK: J6.3; also elsewhere on the board
GND: J6.1, SW1.2 (B), SW2.2 (B); also elsewhere on the board

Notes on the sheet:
ESP-01 Dock
Programmer

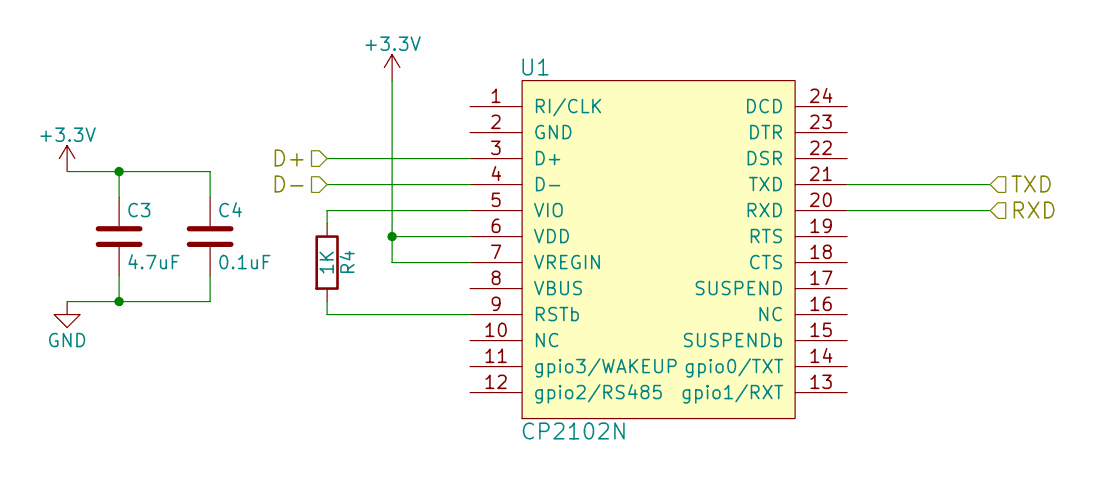
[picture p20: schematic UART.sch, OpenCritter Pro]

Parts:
C3: 4.7uF; C_0805_HandSoldering
C4: 0.1uF; C_0805_HandSoldering
R4: 1K; R_0805_HandSoldering
U1: CP2102N; QFN-24_4x4mm_Pitch0.5mm

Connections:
+3V3: C3.1, C4.1, U1.6 (VDD), U1.7 (VREGIN); also elsewhere on the board
/ESP-01/RX: U1.20 (RXD); also elsewhere on the board
/ESP-01/TX: U1.21 (TXD); also elsewhere on the board
/UART/D+: U1.3 (D+); also elsewhere on the board
/UART/D-: U1.4 (D-); also elsewhere on the board
GND: C3.2, C4.2; also elsewhere on the board
unnamed: R4.1, U1.5 (VIO)
unnamed: R4.2, U1.9 (RSTb)

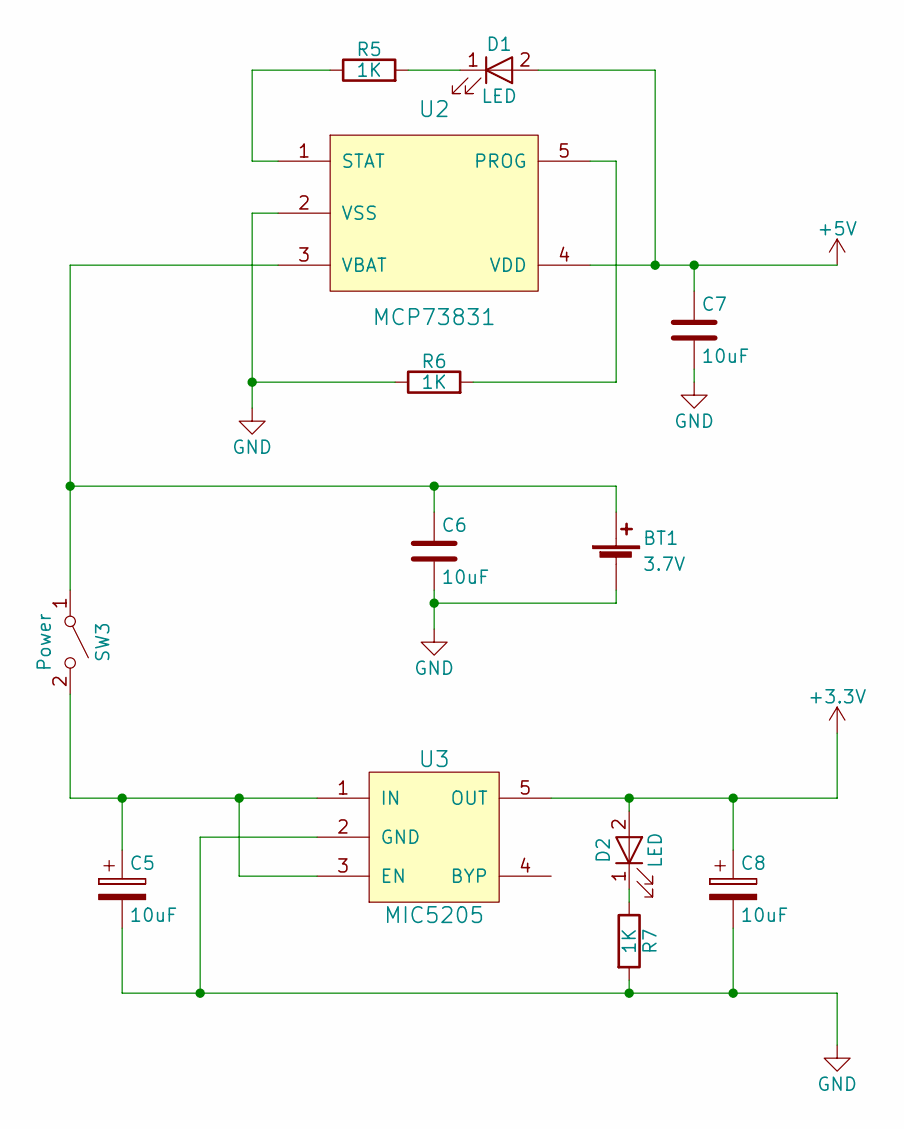
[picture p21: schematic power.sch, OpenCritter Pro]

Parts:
BT1: 3.7V; Pin_Header_Straight_1x02_Pitch2.54mm
C5, C8: 10uF; CP_Tantalum_Case-A_EIA-3216-18_Reflow
C6, C7: 10uF; C_0805_HandSoldering
D1, D2: LED; LED_0805_HandSoldering
R5, R6, R7: 1K; R_0805_HandSoldering
SW3: Power; JS102011JAQN
U2: MCP73831; SOT-23-5_HandSoldering
U3: MIC5205; SOT-23-5_HandSoldering

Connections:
+3V3: C8.1, D2.2 (A), U3.5 (OUT); also elsewhere on the board
+5V: C7.1, D1.2 (A), U2.4 (VDD); also elsewhere on the board
GND: BT1.2 (-), C5.2, C6.2, C7.2, C8.2, R6.1, R7.2, U2.2 (VSS), U3.2 (GND); also elsewhere on the board
unnamed: BT1.1 (+), C6.1, SW3.1 (A), U2.3 (VBAT)
unnamed: C5.1, SW3.2 (B), U3.1 (IN), U3.3 (EN)
unnamed: D1.1 (K), R5.2
unnamed: D2.1 (K), R7.1
unnamed: R5.1, U2.1 (STAT)
unnamed: R6.2, U2.5 (PROG)

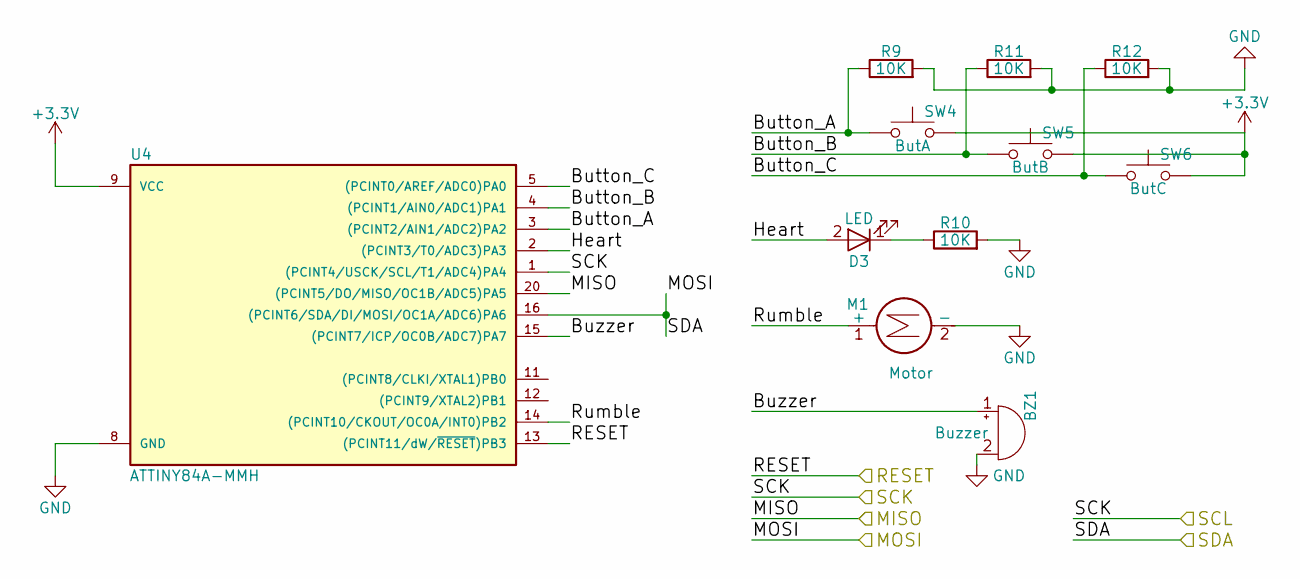
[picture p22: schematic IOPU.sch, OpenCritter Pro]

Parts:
BZ1: Buzzer; Buzzer_12x9.5RM7.6
D3: LED; LED_0805_HandSoldering
M1: Motor; Pin_Header_Straight_1x02_Pitch2.54mm
R9, R10, R11, R12: 10K; R_0805_HandSoldering
SW4: ButA; SW_SPST_B3S-1000
SW5: ButB; SW_SPST_B3S-1000
SW6: ButC; SW_SPST_B3S-1000
U4: ATTINY84A-MMH; QFN-20-1EP_4x4mm_Pitch0.5mm

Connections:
+3V3: SW4.2, SW5.2, SW6.2, U4.9 (VCC); also elsewhere on the board
/IOPU/Button_A: R9.1, SW4.1, U4.3 ((PCINT2/AIN1/ADC2)PA2)
/IOPU/Button_B: R11.1, SW5.1, U4.4 ((PCINT1/AIN0/ADC1)PA1)
/IOPU/Button_C: R12.1, SW6.1, U4.5 ((PCINT0/AREF/ADC0)PA0)
/IOPU/Buzzer: BZ1.1 (-), U4.15 ((PCINT7/ICP/OC0B/ADC7)PA7)
/IOPU/Heart: D3.2 (A), U4.2 ((PCINT3/T0/ADC3)PA3)
/IOPU/Rumble: M1.1 (+), U4.14 ((PCINT10/CKOUT/OC0A/INT0)PB2)
/MISO: U4.20 ((PCINT5/DO/MISO/OC1B/ADC5)PA5); also elsewhere on the board
/MOSI: U4.16 ((PCINT6/SDA/DI/MOSI/OC1A/ADC6)PA6); also elsewhere on the board
/RESET: U4.13 ((PCINT11/dW/~RESET~)PB3); also elsewhere on the board
/SCK: U4.1 ((PCINT4/USCK/SCL/T1/ADC4)PA4); also elsewhere on the board
GND: BZ1.2 (+), M1.2 (-), R9.2, R10.2, R11.2, R12.2, U4.8 (GND); also elsewhere on the board
unnamed: D3.1 (K), R10.1

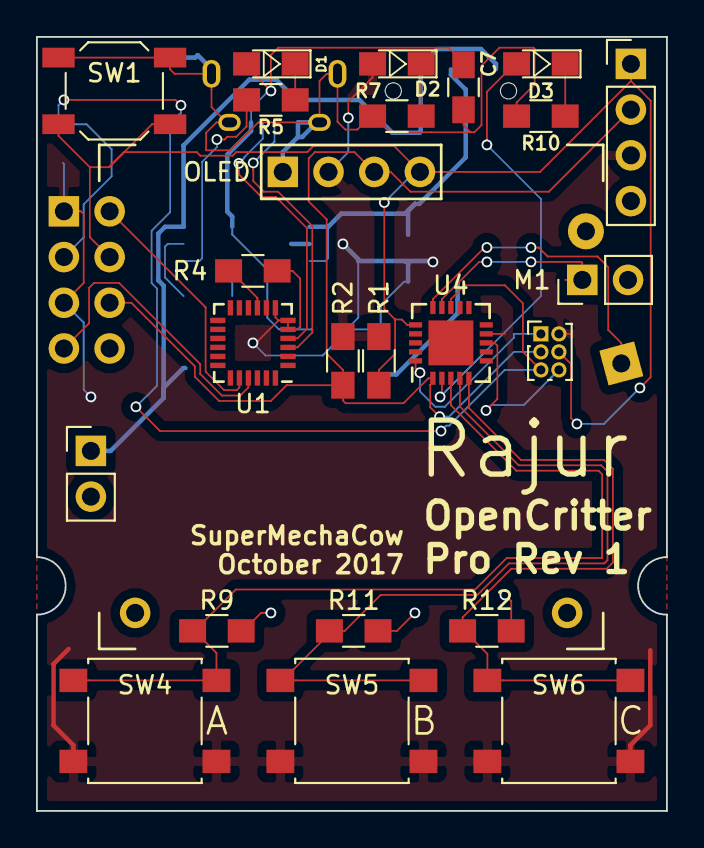
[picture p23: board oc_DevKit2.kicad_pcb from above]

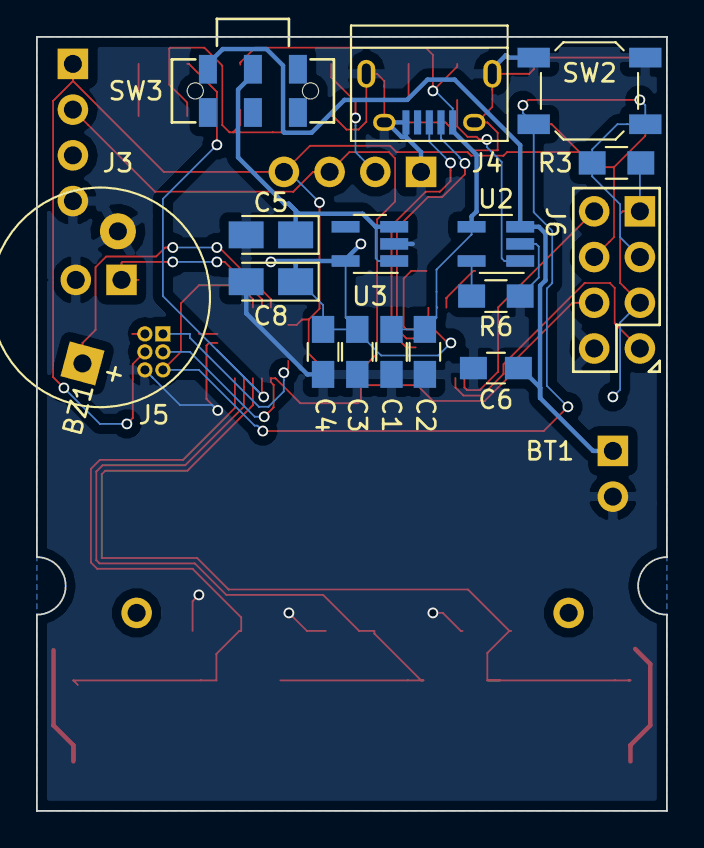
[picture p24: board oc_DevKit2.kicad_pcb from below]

Board: 2 copper layers, 35.0 x 43.0 mm, 40 parts (16 on the bottom side), 26 nets.

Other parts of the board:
C1: 4.7uF; C_0805_HandSoldering
C2: 0.1uF; C_0805_HandSoldering
OLED: OLED; SSD1306_i2c

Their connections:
+3V3: OLED.2; also elsewhere on the board
+5V: C1.1, C2.1; also elsewhere on the board
/MOSI: OLED.4; also elsewhere on the board
/SCK: OLED.3; also elsewhere on the board
GND: C1.2, C2.2, OLED.1; also elsewhere on the board

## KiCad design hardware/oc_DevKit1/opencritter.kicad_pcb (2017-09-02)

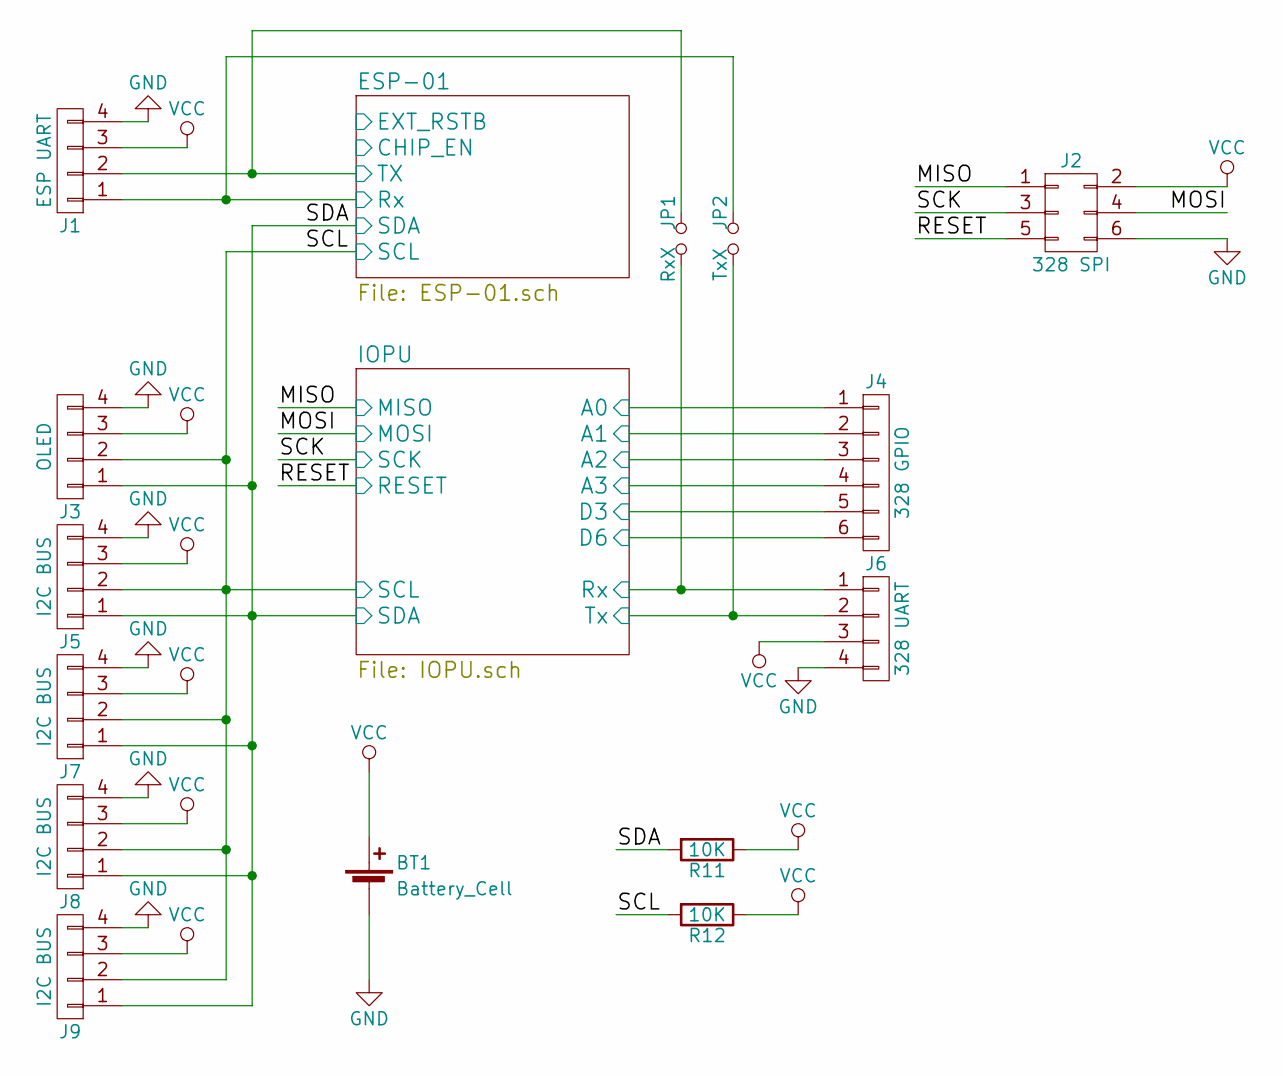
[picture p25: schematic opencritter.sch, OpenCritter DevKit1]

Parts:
BT1: Battery_Cell; Pin_Header_Straight_1x02_Pitch2.54mm
J1: ESP UART; Pin_Header_Straight_1x04_Pitch2.54mm
J2: 328 SPI; Pin_Header_Straight_2x03_Pitch2.54mm
J3: OLED; Pin_Header_Straight_1x04_Pitch2.54mm
J4: 328 GPIO; Pin_Header_Straight_1x06_Pitch2.54mm
J5, J7, J8, J9: I2C BUS; Pin_Header_Angled_1x04_Pitch2.54mm
J6: 328 UART; Pin_Header_Straight_1x04_Pitch2.54mm
JP1: RxX; R_0603
JP2: TxX; R_0603
R11, R12: 10K; R_0805_HandSoldering

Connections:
/ESP-01/Rx: J1.1, JP2.1; also elsewhere on the board
/ESP-01/TX: J1.2, JP1.1; also elsewhere on the board
/IOPU/A0: J4.1; also elsewhere on the board
/IOPU/A1: J4.2; also elsewhere on the board
/IOPU/A2: J4.3; also elsewhere on the board
/IOPU/A3: J4.4; also elsewhere on the board
/IOPU/D3: J4.5; also elsewhere on the board
/IOPU/D6: J4.6; also elsewhere on the board
/IOPU/Rx: J6.1, JP1.2; also elsewhere on the board
/IOPU/Tx: J6.2, JP2.2; also elsewhere on the board
/MISO: J2.1; also elsewhere on the board
/MOSI: J2.4; also elsewhere on the board
/RESET: J2.5; also elsewhere on the board
/SCK: J2.3; also elsewhere on the board
/SCL: J3.2, J5.2, J7.2, J8.2, J9.2, R12.2; also elsewhere on the board
/SDA: J3.1, J5.1, J7.1, J8.1, J9.1, R11.2; also elsewhere on the board
GND: BT1.2 (-), J1.4, J2.6, J3.4, J5.4, J6.4, J7.4, J8.4, J9.4; also elsewhere on the board
VCC: BT1.1 (+), J1.3, J2.2, J3.3, J5.3, J6.3, J7.3, J8.3, J9.3, R11.1, R12.1; also elsewhere on the board

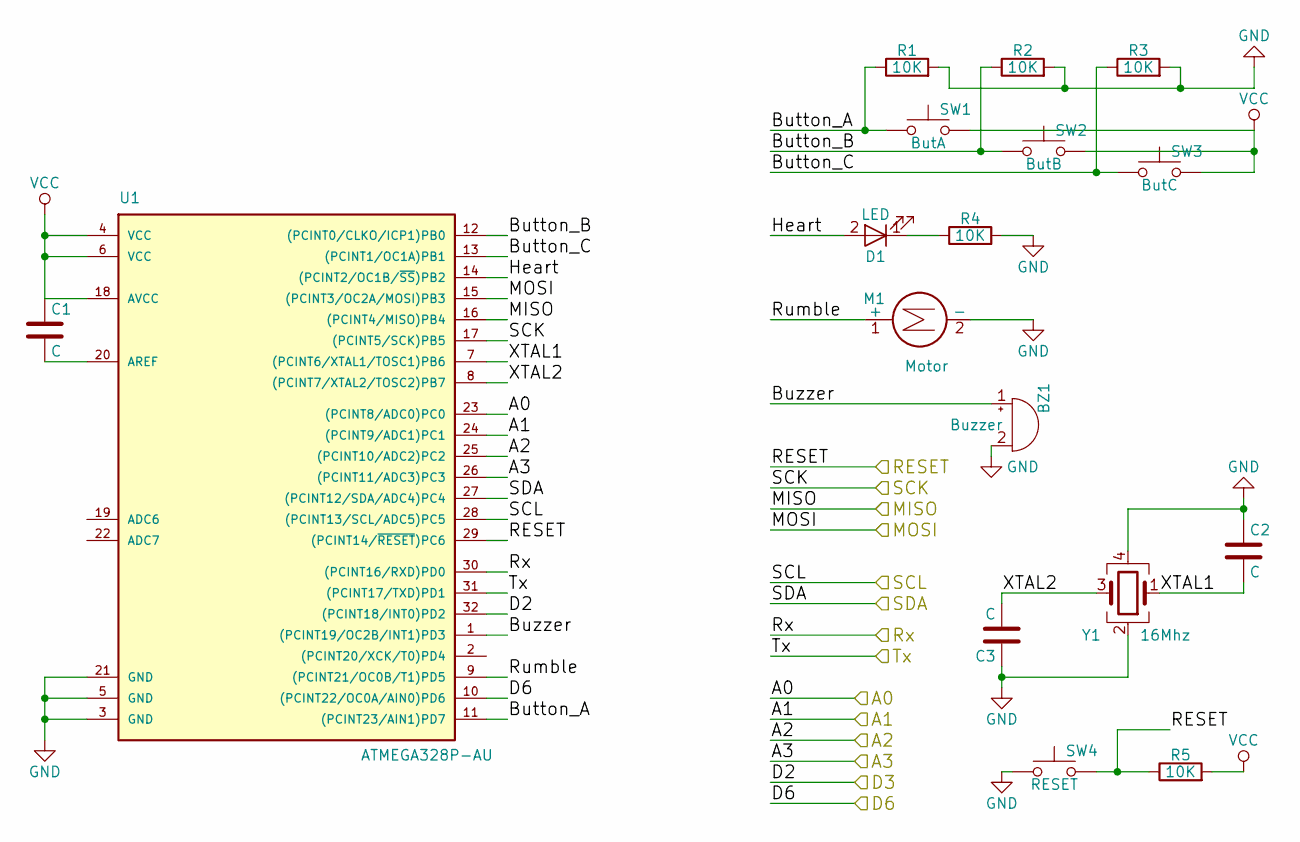
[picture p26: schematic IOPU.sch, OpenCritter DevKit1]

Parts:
BZ1: Buzzer; BUZZER
C1, C2, C3: C; C_0805_HandSoldering
D1: LED; LED_0805_HandSoldering
M1: Motor; Pin_Header_Straight_1x02_Pitch2.54mm
R1, R2, R3, R4, R5: 10K; R_0805_HandSoldering
SW1: ButA; SW_SPST_SKQG
SW2: ButB; SW_SPST_SKQG
SW3: ButC; SW_SPST_SKQG
SW4: RESET; SW_SPST_SKQG
U1: ATMEGA328P-AU; TQFP-32_7x7mm_Pitch0.8mm
Y1: 16Mhz; Crystal_SMD_3225-4pin_3.2x2.5mm_HandSoldering

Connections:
/IOPU/A0: U1.23 ((PCINT8/ADC0)PC0); also elsewhere on the board
/IOPU/A1: U1.24 ((PCINT9/ADC1)PC1); also elsewhere on the board
/IOPU/A2: U1.25 ((PCINT10/ADC2)PC2); also elsewhere on the board
/IOPU/A3: U1.26 ((PCINT11/ADC3)PC3); also elsewhere on the board
/IOPU/Button_A: R1.1, SW1.1, U1.11 ((PCINT23/AIN1)PD7)
/IOPU/Button_B: R2.1, SW2.1, U1.12 ((PCINT0/CLKO/ICP1)PB0)
/IOPU/Button_C: R3.1, SW3.1, U1.13 ((PCINT1/OC1A)PB1)
/IOPU/Buzzer: BZ1.1 (-), U1.1 ((PCINT19/OC2B/INT1)PD3)
/IOPU/D3: U1.32 ((PCINT18/INT0)PD2); also elsewhere on the board
/IOPU/D6: U1.10 ((PCINT22/OC0A/AIN0)PD6); also elsewhere on the board
/IOPU/Heart: D1.2 (A), U1.14 ((PCINT2/OC1B/~SS~)PB2)
/IOPU/Rumble: M1.1 (+), U1.9 ((PCINT21/OC0B/T1)PD5)
/IOPU/Rx: U1.30 ((PCINT16/RXD)PD0); also elsewhere on the board
/IOPU/Tx: U1.31 ((PCINT17/TXD)PD1); also elsewhere on the board
/IOPU/XTAL1: C2.2, U1.7 ((PCINT6/XTAL1/TOSC1)PB6), Y1.1
/IOPU/XTAL2: C3.2, U1.8 ((PCINT7/XTAL2/TOSC2)PB7), Y1.3
/MISO: U1.16 ((PCINT4/MISO)PB4); also elsewhere on the board
/MOSI: U1.15 ((PCINT3/OC2A/MOSI)PB3); also elsewhere on the board
/RESET: R5.1, SW4.2, U1.29 ((PCINT14/~RESET~)PC6); also elsewhere on the board
/SCK: U1.17 ((PCINT5/SCK)PB5); also elsewhere on the board
/SCL: U1.28 ((PCINT13/SCL/ADC5)PC5); also elsewhere on the board
/SDA: U1.27 ((PCINT12/SDA/ADC4)PC4); also elsewhere on the board
GND: BZ1.2 (+), C2.1, C3.1, M1.2 (-), R1.2, R2.2, R3.2, R4.2, SW4.1, U1.3 (GND), U1.5 (GND), U1.21 (GND), Y1.2, Y1.4; also elsewhere on the board
unnamed: C1.2, U1.20 (AREF)
unnamed: D1.1 (K), R4.1
VCC: C1.1, R5.2, SW1.2, SW2.2, SW3.2, U1.4 (VCC), U1.6 (VCC), U1.18 (AVCC); also elsewhere on the board

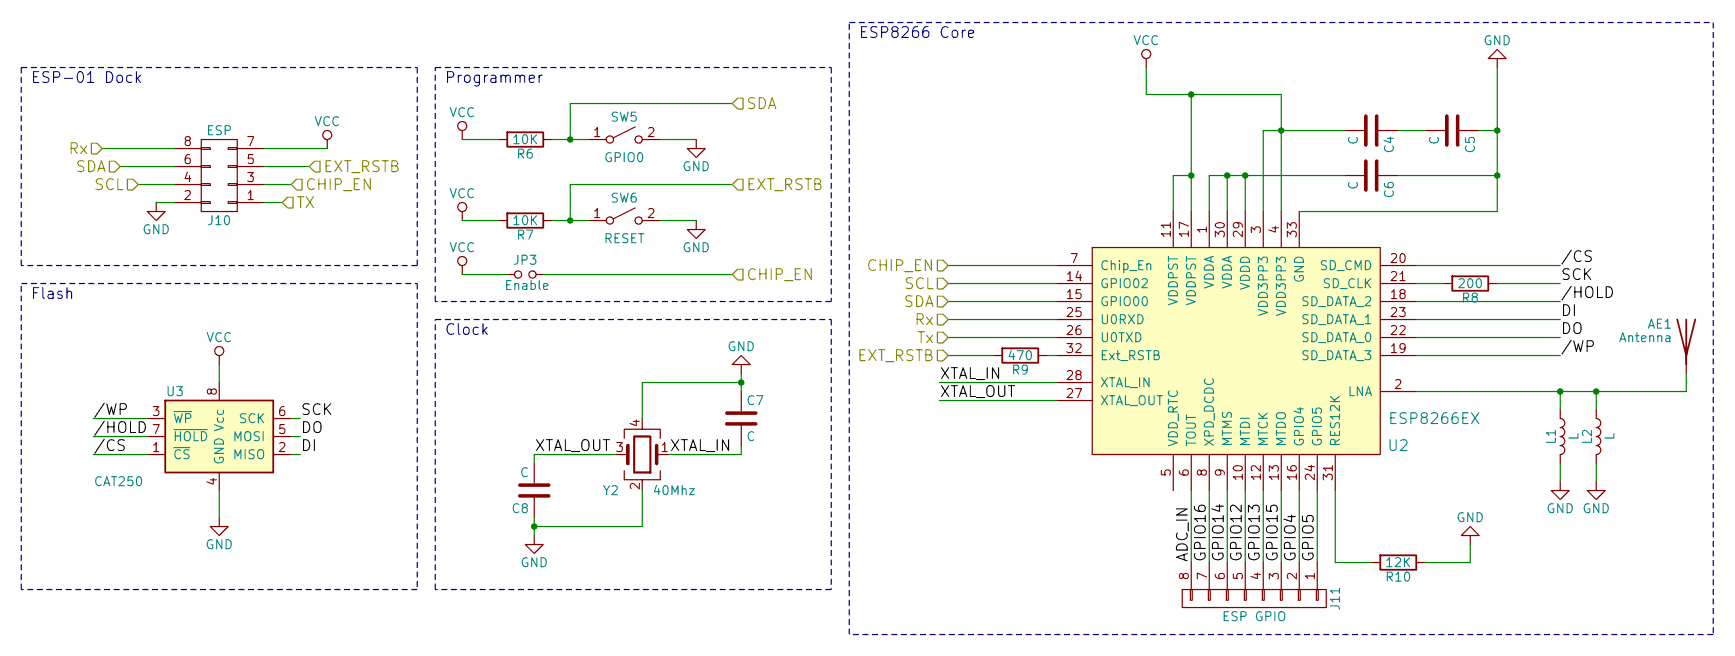
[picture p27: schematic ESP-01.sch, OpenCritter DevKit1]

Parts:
AE1: Antenna; Pin_Header_Straight_1x01_Pitch2.54mm
C4, C5, C6, C7, C8: C; C_0805_HandSoldering
J10: ESP; Pin_Header_Straight_2x04_Pitch2.54mm
J11: ESP GPIO; Pin_Header_Straight_1x08_Pitch2.54mm
JP3: Enable; R_0603
L1, L2: L; L_0805_HandSoldering
R6, R7: 10K; R_0805_HandSoldering
R8: 200; R_0805_HandSoldering
R9: 470; R_0805_HandSoldering
R10: 12K; R_0805_HandSoldering
SW5: GPIO0; SW_SPST_EVQPE1
SW6: RESET; SW_SPST_EVQPE1
U2: ESP8266EX; QFN-32-1EP_5x5mm_Pitch0.5mm
U3: CAT250; SOIC-8_3.9x4.9mm_Pitch1.27mm
Y2: 40Mhz; Crystal_SMD_3225-4pin_3.2x2.5mm_HandSoldering

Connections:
/ESP-01//CS: U2.20 (SD_CMD), U3.1 (~CS)
/ESP-01//HOLD: U2.18 (SD_DATA_2), U3.7 (~HOLD)
/ESP-01//WP: U2.19 (SD_DATA_3), U3.3 (~WP)
/ESP-01/ADC_IN: J11.8, U2.6 (TOUT)
/ESP-01/CHIP_EN: J10.3, JP3.2, U2.7 (Chip_En)
/ESP-01/DI: U2.23 (SD_DATA_1), U3.2 (MISO)
/ESP-01/DO: U2.22 (SD_DATA_0), U3.5 (MOSI)
/ESP-01/EXT_RSTB: J10.5, R7.1, R9.2, SW6.1 (A)
/ESP-01/GPIO4: J11.2, U2.16 (GPIO4)
/ESP-01/GPIO5: J11.1, U2.24 (GPIO5)
/ESP-01/GPIO12: J11.5, U2.10 (MTDI)
/ESP-01/GPIO13: J11.4, U2.12 (MTCK)
/ESP-01/GPIO14: J11.6, U2.9 (MTMS)
/ESP-01/GPIO15: J11.3, U2.13 (MTDO)
/ESP-01/GPIO16: J11.7, U2.8 (XPD_DCDC)
/ESP-01/Rx: J10.8, U2.25 (U0RXD); also elsewhere on the board
/ESP-01/SCK: R8.1, U3.6 (SCK)
/ESP-01/TX: J10.1, U2.26 (U0TXD); also elsewhere on the board
/ESP-01/XTAL_IN: C7.2, U2.28 (XTAL_IN), Y2.1
/ESP-01/XTAL_OUT: C8.2, U2.27 (XTAL_OUT), Y2.3
/SCL: J10.4, U2.14 (GPIO02); also elsewhere on the board
/SDA: J10.6, R6.1, SW5.1 (A), U2.15 (GPIO00); also elsewhere on the board
GND: C5.1, C6.1, C7.1, C8.1, J10.2, L1.2, L2.2, R10.1, SW5.2 (B), SW6.2 (B), U2.33 (GND), U3.4 (GND), Y2.2, Y2.4; also elsewhere on the board
unnamed: AE1.1, L1.1, L2.1, U2.2 (LNA)
unnamed: C4.1, C5.2
unnamed: C6.2, U2.1 (VDDA), U2.29 (VDDD), U2.30 (VDDA)
unnamed: R8.2, U2.21 (SD_CLK)
unnamed: R9.1, U2.32 (Ext_RSTB)
unnamed: R10.2, U2.31 (RES12K)
VCC: C4.2, J10.7, JP3.1, R6.2, R7.2, U2.3 (VDD3PP3), U2.4 (VDD3PP3), U2.11 (VDDPST), U2.17 (VDDPST), U3.8 (Vcc); also elsewhere on the board

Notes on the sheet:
ESP-01 Dock
Flash
Clock
Programmer
ESP8266 Core

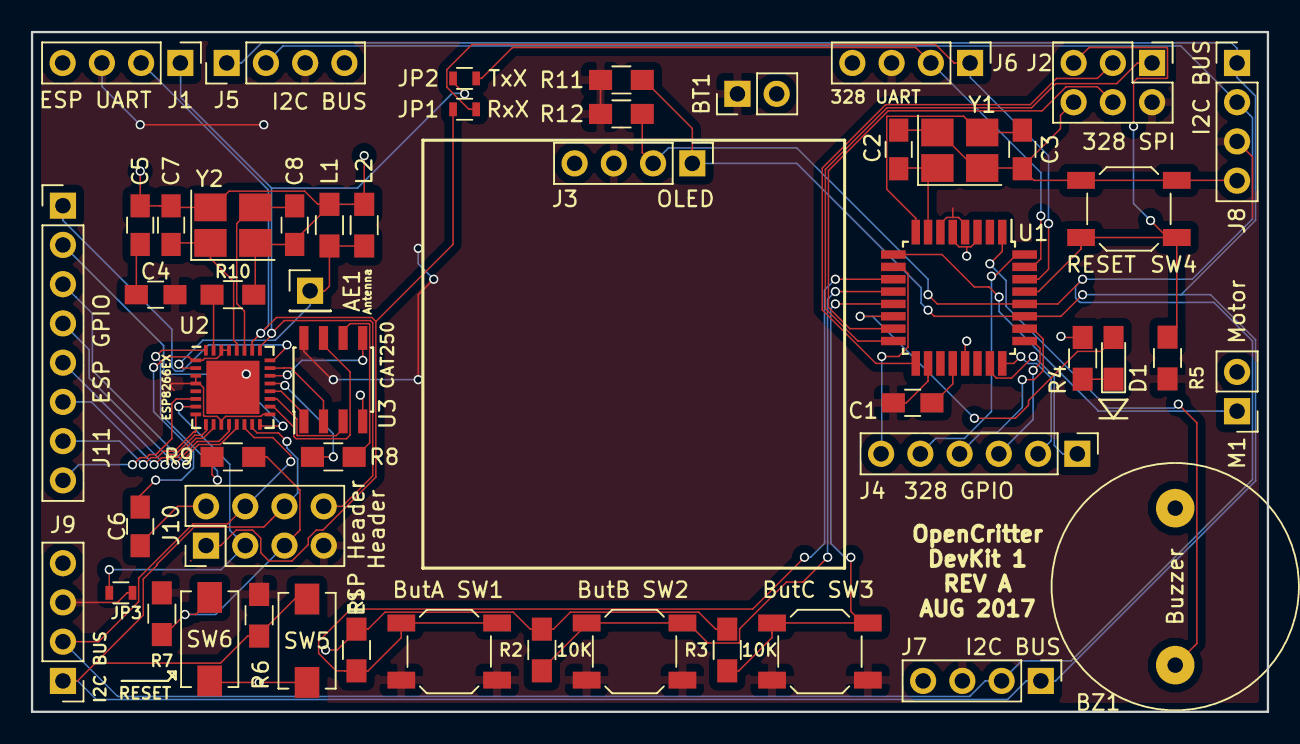
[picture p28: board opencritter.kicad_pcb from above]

Board: 2 copper layers, 80.0 x 44.0 mm, 52 parts (0 on the bottom side), 52 nets.

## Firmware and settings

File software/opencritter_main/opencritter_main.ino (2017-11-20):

#include <Wire.h>
//#include <U8g2lib.h>
#include <Adafruit_SSD1306.h>
#include <ESP8266WiFi.h>
#include <WiFiClient.h>
#include <ESP8266WebServer.h>

//Include custom files
#include "A_labels.h"
#include "B_boardselect.h"
#include "C_setup.h"
#include "Z_gfx.h"
#include "Z_strings.h"

//
// All of the variable declarations are in _setup.h
//

void setup()
{
  if (mcuinputs) {
    pinMode(hrt_pin, OUTPUT);
    pinMode(Abut_pin, INPUT);
    pinMode(Bbut_pin, INPUT);
    pinMode(Cbut_pin, INPUT);
    pinMode(beeper_pin, OUTPUT);
    pinMode(rumble_pin, OUTPUT);
    IOPUattached = false;
  }
  else {
    IOPUattached = true;
  }

  /*== Start Comms =========================================================================================================*/

  delay(2000); // Wait for other devices to boot.

  //Set the pins for I2C if using esp8266
  Wire.begin(i2cSDA, i2cSCL);

  //Spin up a serial port for debugging/comms
  Serial.begin(serialbaud);

  //Find all of the i2c devices on the bus and start registering them
  //i2c_scanbus();

  /*== Start Graphics ======================================================================================================*/

  if (!GPUattached) { //If there's no GPU, do your own graphics
    // start an OLED screen object
    display.begin(SSD1306_SWITCHCAPVCC, OLED_device);
    // Display the buffer image
    display.display();
    // Clear the buffer
    display.clearDisplay();
  }

  /*== Misc. Setup =========================================================================================================*/

  //Reset the seed
  randomSeed(analogRead(0));

  metaBonus = egg_m;

  /*== Animation Setup =====================================================================================================*/

  //Get the starting variables ready for the various functions
  selMenu = m_main;            //Start the menus with the "Main Menu" play screen
  aniMode = a_idle;  //First animation to play is the egg
  aniStage = RESET;           //prime animation stage
  aniLast = RESET;            //Set the placeholder for previous animation

  beep(beep_UpChirp);         //Hello World!

  updateScreen();             //draw the first screen

  /*== WebAP Setup =========================================================================================================*/

  //  We set the default state in the firmware for this. This is actually incredibly touchy and inconsistent.
  //  If we don't explicitly shut the WiFi off, it uses 50mA more current as if it's broadcasting, even after reset.

  if (wifiEnabled) {
    WiFiMode(WIFI_AP);                  //Set WiFi mode to Access Point
    WiFi.softAP(ssid, password);        //Start a WiFi AP with this Name and Password
    IPAddress myIP = WiFi.softAPIP();   //Make it assign it's own default IP address (192.168.4.1)
    server.on("/", handleRoot);         //Run handleroot() if the URL after the IP is just "/" (Root. '192.168.4.1/')
    server.begin();                     //Start a
  }
  else {
    WiFiMode(WIFI_STA);                 //Set the mode to Station, so it's not constantly broadcasting
    WiFi.disconnect();                  //If there is any connection, stop it.
    WiFi.mode(WIFI_OFF);                //The official command to turn WiFi off, but it doesn't seem to work
    WiFi.forceSleepBegin();             //So we force the WiFi portion of the chip to sleep
    delay(100);                         //If Arduino code tries to run before the sleep is complete, it won't work at all
  }

  /*== End Setup ===========================================================================================================*/

  //If the debugging is on, let the user know over serial
  if (debugMode) {
    Serial.println(F("Ready for command..."));
    Energy = 255;  //I don't want to wait for energy to build up to test-play games
    beepMute = true;  //These get annoying after awhile
  }

}

void loop() {

  //Handle the web server if wifi is enabled
  if (wifiEnabled)
    server.handleClient();

  if (!deadcritter) {

    /*== Start Loop ==========================================================================================================*/



    /*== Heartbeat Events ====================================================================================================*/


    /*HEARTBEATS AND CLOCK CHECKING
       The timing in this game is linked to Metabolism and Heartbeats, which are the frequency of "game ticks", respectively.
       There are several "Clocks" in the code that track when various functions should continue to the next "stage".

       Certain events happen every "X" heartbeats. Most hearbeats won't do anything, but some will "roll" or "roll the dice" on
       an event taking place. "Rolling" determines the result of something based on the critter's parameters. For example, every
       pre-defined set of heartbeats the game will roll to see if a health stat will drain. The higher the creature's power stat, the less
       likely it will drain a health stat.
    */

    CLK[baseCLK] = millis(); //Update clock to the current millisecond
    if ((CLK[baseCLK] - CLK[hrtCLK]) > (baseHRT_speed * metabolism)) //If at least one heartbeat time increment has passed since we last checked
    {
      //Add as many heartbeats to the "queue" as increments
      queueBeats = ((CLK[baseCLK] - CLK[hrtCLK]) / (baseHRT_speed * metabolism));

      for (int i = 0; i < queueBeats; i++) { //For each heartbeat that has happened since we last checked we have to "roll" for changes

        heartbeats++; //Add one heartbeat before we "roll" each loop
        if (Alert)
          distressbeats++;

        //Calculate metabolism
        //Start with average value of health mapped to 0 to 100
        metabolism = map(getHealth(), 0, max_health, 100, 0);;
        //Add in average value of power and invert the value
        metabolism = metabolism + map(getPower(), 0, max_power, 100, 0);
        //Add in metabolism bonus from breed
        metabolism = metabolism + metaBonus;
        //Take the average of the prior three values
        metabolism = metabolism / 3;
        //Modulate by how far away from a healthy weight the critter is
        metabolism = metabolism + abs(weight - nominal_w);
        if (boostActive) {
          if (boostBeat <= heartbeats)
            boostActive = false;
          else
            metabolism = metabolism * sodaBonusMulti;
        }
        //Make sure metabolism is at least 1 or else we will be dividing by zero later on and ripping holes in the universe
        if (metabolism <= 0)
          metabolism = 1;
        if (metabolism > max_metabolism)
          metabolism = max_metabolism;

        //Calculate the sickness threshold
        sick_thresh = (sick_multi * (poopCount + sickCount + lifestage)) + sick_base;
        if (sick_thresh > 255)
          sick_thresh = 255;

        //Each opencritter has three temporary health stats and three "power stats"
        //Each power stat evolves over time and effects short term change of health
        //Raising the power stat decreases the drain rate of the status
        //Raising a health stat with junk foods negatively impact power stats
        //Power stats also each effect one other part of the game
        //Every beat_health number of heartbeats the game "rolls" to decrease a health stat

        //CALCULATE STAT CHANGE
        //The game "rolls the dice" (picks a number between 0 and max_drainChance)
        //If the roll is higher than that health stat's related power stat, it reduces the health stat by 1
        //The higher the power stat, the less likely there will be a health reduction
        //Sickness lowers the power temporarily. This is calculated by how many stacks of sickness it has times the sickness penalty multiplier

        if (heartbeats % beat_health == 0) { //If the current heartbeat is a key beat for rolling for health stat drain
          if (random(0, max_drainChance) > Ath - (sick_penalty * sickCount)) { //High power stats reduce chance of health stat drain. Each stack of sickness increases chance.
            if (hun > 0)
              hun--; //hunger = athleticism
            if (Energy < max_energy)
              Energy++;
            beep(beep_Tick);
          }
          if (random(0, max_drainChance) > Dis - (sick_penalty * sickCount)) {
            if (hap > 0)
              hap--; //happiness = Dis
            if (Energy < max_energy)
              Energy++;
            beep(beep_Tick);
          }
          if (random(0, max_drainChance) > Int - (sick_penalty * sickCount)) {
            if (bor > 0)
              bor--; //boredom = Int
            if (Energy < max_energy)
              Energy++;
            beep(beep_Tick);
          }
        }

        //See if it will cry wolf
        if (heartbeats % beat_cry == 0) { //If this is a key
          cryHandler();
        }

        //Check for sickness
        if (heartbeats % beat_sick == 0) {
          sickHandler();
        }

        //Check for poop
        if (heartbeats % beat_poop == 0) {
          poopHandler();
        }

        //Check to see if it has hatched
        if (heartbeats % beat_hatch == 0 && breed == 0) {
          evolveHandler();
        }

        //Check for evolution
        if (heartbeats % beat_evolve == 0) {
          evolveHandler();
        }

        //Check for a discovery
        if (Energy == max_energy && breed != egg) {
          discovery();
        }

        if (heartbeats % beat_energy == 0 && Energy != max_energy) {
          Energy++;
        }

        //Change the position of the critter (not egg) to be written when the main menu is being shown (see H_menus)
        //This is otherwise known as moving around the "playpen"
        if (breed != egg && breed != crosh) {
          //playPen_then = playPen_now;
          playPen_now = playPen_now + random(-8, 9);
          if (playPen_now < pp_min)
            playPen_now = pp_min;
          if (playPen_now > pp_max)
            playPen_now = pp_max;
        }

      }

      //Update the IOPU with the heartbeat state
      sendhrtpin();

      CLK[hrtCLK] = CLK[baseCLK];              //Set last heart beat clock to current clock

    }

    /*== Update other devices =================================================================================================*/

    //theQ();

    //Comment out for NODEMCU
    updateIOPU();

    getButtons();

    debug();

    /*== Call the current menu ================================================================================================*/

    //Call the right menu function depending on what the current menu variable is set to (selMenu)
    switch (selMenu)
    {
      //
      // Menus
      case m_main:
        mainMenu();
        break;
      case m_clock:
        clockMenu();
      case m_stats:
        statsMenu();
        break;
      case m_food:
        foodMenu();
        break;
      case m_conf:
        confMenu();
        break;
      case m_play:
        playMenu();
        break;
      case m_invent:
        inventMenu();
        break;
      case m_detail:
        detailMenu();
        break;
      case m_clockset:
        clockSet();
        break;
      case m_pedia:
        pediaMenu();
        break;
      //
      // Games
      case g_ballcatch:
        ballcatch();
        break;
      case g_cardflip:
        cardflip();
        break;
      case g_bitshifter:
        bitshifter();
        break;
      case g_lazerjet:
        lazerjet();
        break;
      default:
        break;
    }

    /*== Turn off OLED if inactive ============================================================================================*/

    // If the player hasn't touched the device since longer than the timeout number AND the device is not already sleeping
    // (we add ten to make sure the clock has had time to update since the last button press
    if (((CLK[baseCLK] + 10) - CLK[sleepCLK]) > sleepTimeout && !deviceSleep) {
      display.ssd1306_command(SSD1306_DISPLAYOFF);  //Tell the OLED to sleep
      deviceSleep = true; //Let the device know it's already sleeping, so it won't try to make it sleep again
    }
    else if ((CLK[baseCLK] - CLK[sleepCLK]) < sleepTimeout && deviceSleep) { // The player HAS touched it recently
      display.ssd1306_command(SSD1306_DISPLAYON);  //Tell the OLED to wake up
      deviceSleep = false; //Let the device know it's already awake, so it won't try to make it wake up again
    }

  }

  /*== Don't do anything if critter is dead ===================================================================================*/

  else {
    delay(1);
  }
}

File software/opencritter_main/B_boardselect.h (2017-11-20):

//ocLite on an Arduino standalone
#ifdef __Atmega328__
//Load ocLite
#endif

//oc on ESP-01 with Arduino I/O Processing Unit
#ifdef ESP8266
#define oc_esp8266  true
#define mcuinputs  false
//load related libraries
#include <WiFiClient.h>
#include <ESP8266WebServer.h>
#include <ESP8266WiFi.h>
//declare pin numbers
#define hrt_pin     0
#define Abut_pin    0
#define Bbut_pin    0
#define Cbut_pin    0
#define beeper_pin  0
#define rumble_pin  0
//i2c and uart comms
#define i2cSDA      0
#define i2cSCL      2
#define serialbaud  500000
#endif

//oc on NodeMCU standalone
#ifdef ARDUINO_ESP8266_NODEMCU
#define oc_esp8266 false
#define mcuinputs true
//Input/Output Pins
#define hrt_pin     D5   //D5 14
#define Abut_pin    D0   //D0 16
#define Bbut_pin    D1   //D1 5
#define Cbut_pin    D3   //D2 4
#define beeper_pin  D4   //D6 12
#define rumble_pin  D8   //D8 13
//i2c and uart comms
#define i2cSDA      D6
#define i2cSCL      D7
#define serialbaud  115200
#endif

#ifdef __AVR_ATmega2560__
#define oc_esp8266 false
#define mcuinputs true
//Input/Output Pins
#define hrt_pin     10
#define Abut_pin    7
#define Bbut_pin    8
#define Cbut_pin    9
#define beeper_pin  6
#define rumble_pin  3
#define serialbaud  115200
#endif

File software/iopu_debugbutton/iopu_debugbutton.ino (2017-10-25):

#include <Wire.h>

//Include custom files
#include "A_labels.h"
#include "B_boardselect.h"
#include "C_setup.h"

void setup()
{
  //Spin up a comm port
  if (debugMode)
    Serial.begin(serialbaud);

  //Start the I2C slave and give it an address
  Wire.begin(i2c_addr);
  Wire.onReceive(receiveEvent);
  Wire.onRequest(requestEvent);

  //Set pin modes for the input tactile switches
  pinMode(Abut_pin, INPUT);
  pinMode(Bbut_pin, INPUT);
  pinMode(Cbut_pin, INPUT);
  //Debugger button
  pinMode(Dbut_pin, INPUT);

  //Set the heartbeat, speaker, and rumble motor to outputs
  pinMode(hrt_pin, OUTPUT);
  pinMode(beeper_pin, OUTPUT);
  pinMode(buzzer_pin, OUTPUT);

  beepMode = beep_UpChirp;

}

void loop()
{
  CLK[baseCLK] = millis(); //Update clock to the current millisecond

  //add2Q(Q_metabolism);
  Qrequests[0] = Q_metabolism;

  if (!beepMute)
    beep();
  if (!buzzMute)
    buzz();
  //if (debugMode)
  //debug();
}

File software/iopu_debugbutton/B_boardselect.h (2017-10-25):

//#ifdef __AVR_ATmega328P__
// IO Pins
#define hrt_pin           10
#define Abut_pin          7       //These are switched for devkit1
#define Bbut_pin          8       
#define Cbut_pin          9       //These are switched for devkit1
#define Dbut_pin          15      //DevKit1 debug button
#define buzzer_pin        6
#define beeper_pin        3
//Unused pins: 2, 4, 6 (11, 12, 13 for SPI)
// i2c and uart comms
#define i2c_addr          IOPU_Atmega328
#define serialbaud        115200
//#endif

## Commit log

2017-06-27 Basic Clock Update
    Added a clock set option in the configuration menu. Clock menu now shows real time and lifespan seperately.
    [oc_Atmega328.fzz, oc_IO.sch, oc_amplifiers.sch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]
2017-06-29 EEPROM (internal) Update
    Moved GFX to internal EEPROM.
    [oc_Atmega328.fzz]
2017-09-02 DevKit1 Prep Update
    Added files for the upcoming DevKit1
    [BOM.xlsx, ESP-01.sch, IOPU.sch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]
2017-09-13 DevKit1 Release
    Added many new features and optimization for the new DevKit1
    [BOM.xlsx, ESP-01.sch, costs.ods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]
2017-09-30 Teen critter update
    Added teenagers to the game. Fixed up mini-games.
    [BOM.xlsx, ESP-01.sch, ESP8266-ESP01.stp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]
2017-10-19 Inventory Update
    Reworked stats, added new graphics, added inventory, updated energy system, reworked animation system.
    [oc_DevKit2-B.Cu.gbl, oc_DevKit2-B.Mask.gbs, oc_DevKit2-B.Paste.gbp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]
2017-10-25 Adult Update
    Added 9 new adults, added various fixes. Untested patch!
    [B_boardselect.h, D_debug.ino, E_InputOutput.ino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]
2017-11-20 Lil Patch
    Small changes. Updating for forthcoming Lite branch updates
    [IOPU.sch, UART.sch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]
